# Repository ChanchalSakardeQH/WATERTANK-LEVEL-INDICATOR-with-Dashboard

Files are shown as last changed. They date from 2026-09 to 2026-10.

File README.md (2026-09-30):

<p align="center">
  <a href="https://woodyouloveit.com">woodyouloveit.com</a>
</p>

# Water Tanks Monitor System

**by [woodyouloveit.com](https://woodyouloveit.com)** · © 2026 Chanchal Sakarde. All Rights Reserved. · Open source under [GPL-3.0](LICENSE)

A tank water level indicator using a waterproof ultrasonic sensor, a WS2812B LED strip (1–300 LEDs) and a built-in web dashboard.
The strip fills from the bottom as the water rises: **red at the bottom, fading through yellow to green at the top**.

One sketch runs on both **ESP32 DevKit V1 (30-pin)** and **NodeMCU ESP8266 (30-pin)**. The board is detected automatically from the Arduino IDE board selection.

## Features

- **Web dashboard** for desktop and mobile browsers: live level, calibration, display settings, Wi-Fi settings
- **Usage & tank setup**: Domestic or Commercial, tank location (overhead, loft/bathroom, underground sump), shape and size, with loft tank presets and recommended settings for each
- **Calibration without emptying the tank**: slide to how full the tank is now, or enter measurements. The water depth does the rest.
- **Power saving for production** (default): CPU 80 MHz, fewer sensor reads, LED updates only on change, Wi-Fi power saving, adjustable transmit power, and an on-demand hotspot using the BOOT button
- **Site details**: name each device by society or organisation, building and tank. The names appear on the dashboard, PDF reports and logs, and give every tank its own hotspot name and web address.
- **Wi-Fi setup hotspot** ("WTMS-XXXX", or "WTMS <building> <tank>" once named): connect and the dashboard opens automatically (captive portal)
- **Wi-Fi settings in the dashboard**: scan, connect, forget. The hotspot comes back by itself if home Wi-Fi is unreachable.
- **One-tap calibration** from the dashboard ("Tank is EMPTY now" / "Tank is FULL now") or by typing distances
- **Admin and viewer access**: anyone on the network sees Overview and Analytics; changing settings, logs, clearing history and restarting need the admin password
- **Units**: mm, cm or inches for every measurement (device default, and each viewer can pick their own)
- **Firmware update over Wi-Fi (OTA)** from the dashboard, with board and version checks
- **Update rate profiles**: Eco (default: sensor every 5 s), Balanced, Responsive or Custom
- **Settings backup**: export and import all settings as a file, with a Settings ID printed in reports
- **PDF report** of the analytics, branded with the woodyouloveit.com logo and website ([sample](docs/sample_report.pdf))
- **Tank analytics**: level history, motor run time (fill detection), time to fill, water used per day and by hour, night leak check
- **Connectivity log** saved in flash: restarts and their cause, Wi-Fi and hotspot events, sensor faults, health checks
- Settings saved in flash, kept after restarts and power cuts
- LEDs keep showing the level while the setup hotspot is open
- Works on ESP32 and ESP8266 without code changes
- Red → yellow → green gradient bar, with the top LED partially dimmed for smooth movement
- Median filter (7 samples) plus smoothing to ignore ripples and stray echoes
- Low-water alarm: the bottom 3 LEDs blink red below 10%
- Sensor fault indication: the bottom LED blinks blue. A failed reading never shows a false "full" tank.
- Optional mode where the whole bar changes color with the level
- Serial output of distance and level for calibration

## Hardware

| Qty | Part | Notes |
|---|---|---|
| 1 | ESP32 DevKit V1 (30-pin) **or** NodeMCU ESP8266 (30-pin) | |
| 1 | JSN-SR04T or AJ-SR04M waterproof ultrasonic sensor | Driver board + probe |
| 1 | WS2812B LED strip, 30 or 60 LEDs (1–300 supported) | 5V version. Set the count in the dashboard. |
| 1 | 5V power supply: 2A for 30 LEDs, 3A for 60 LEDs | Powers the board, strip and sensor. The dashboard shows the estimate for your setup. |
| 1 | 330Ω resistor | In series with the LED data line |
| 1 | 1kΩ resistor | Echo voltage divider |
| 1 | 2kΩ resistor | Echo voltage divider |
| 1 | 1000µF capacitor, 10V or higher | Across the strip's 5V and GND |
| 2 | 15-pin female headers | Makes the board removable |
| 3 | Screw terminals (4-pin, 3-pin, 2-pin) | Sensor, LED strip, power |
| 1 | Perfboard, about 7×9 cm | |

## Wiring

### Pin summary

| Connection | ESP32 DevKit | NodeMCU ESP8266 | Notes |
|---|---|---|---|
| LED strip DIN | G16 | D2 (GPIO4) | Through the 330Ω resistor |
| Sensor TRIG (AJ-SR04M RX) | D15 | D5 (GPIO14) | Direct |
| Sensor ECHO (AJ-SR04M TX) | D2 | D6 (GPIO12) | ESP32: direct, sensor on 3V3. ESP8266: 1k/2k divider, or direct with the sensor on 3V3 |
| Sensor power | 3V3 | VIN or 3V3 | ESP32: 3V3 only, see below |
| +5V | VIN | VIN | From the 5V supply |
| GND | GND | GND | All grounds connected together |

### ESP32 DevKit V1 (30-pin)

On the ESP32 the sensor uses four neighbouring pins, **3V3 · GND · D15 · D2**, so one 4-pin connector or a short row of jumper wires does the job:

| ESP32 pin | AJ-SR04M pin |
|---|---|
| 3V3 | 5V (runs fine on 3.3V) |
| GND | GND |
| D15 | RX (TRIG) |
| D2 | TX (ECHO) |

ESP32 wiring diagram

> **Keep D15 = TRIG and D2 = ECHO, and power the sensor from 3V3.** D15 and D2 are boot "strapping" pins that the ESP32 reads at start-up.
> D2 must be LOW while uploading over USB. The sensor's echo output rests LOW, so uploads work. The sensor's RX input could hold D2 HIGH, so swapping the two wires can make uploads fail.
> With the sensor on 3V3, the echo is 3.3V and needs no divider. Powering the sensor from 5V would put 5V into D2.
> If your board has a blue LED on D2, it will flicker with each measurement. That's normal.
> If an upload ever fails with "wrong boot mode", unplug the sensor connector, upload, and plug it back in.

### NodeMCU ESP8266 (30-pin)

NodeMCU ESP8266 wiring diagram

### NodeMCU ESP8266 with AJ-SR04M on 3.3V (no divider)

The AJ-SR04M is rated for 3.0–5.5V. Powered from the NodeMCU's 3V3 pin, its echo output is 3.3V, so it can connect directly to D6 with no resistors. On this board, **RX = TRIG** and **TX = ECHO**. Range may be shorter than at 5V, so test at your tank's full depth.

NodeMCU ESP8266 3.3V wiring diagram

> **Warning:** In this setup the sensor's 5V pin must go to **3V3 only**. Connecting it to the 5V supply would put 5V straight into D6.

### Why the extra parts

- **1k/2k divider on ECHO:** The sensor's echo output is 5V, but both boards are 3.3V chips. The divider brings the signal down to about 3.3V.
- **330Ω on DIN:** Reduces ringing on the data line and protects the first LED. Place it close to the strip.
- **1000µF capacitor:** Absorbs the current surge when the strip switches on. Mind the polarity: the striped side goes to GND.
- **External 5V supply:** Each LED can draw up to 60mA at full white, so 60 LEDs can need over 3A. The level display uses less (red/green only), and the dashboard shows an estimate for your LED count and brightness. Don't power the strip from the board's USB port.

> **ESP8266 note:** Avoid D3, D4 and D8 for external wiring. The board reads them at boot, and anything connected there can stop it from starting.

## Software setup

1. Install the [Arduino IDE](https://www.arduino.cc/en/software).
2. Add the board package for your board:
   - **ESP32:** In Boards Manager, install "esp32" by Espressif.
   - **ESP8266:** In Preferences → Additional Boards Manager URLs, add
     `http://arduino.esp8266.com/stable/package_esp8266com_index.json`,
     then install "esp8266" from Boards Manager.
3. Install **Adafruit NeoPixel** from Library Manager. Wi-Fi, web server, DNS and mDNS come with the board package.
   The WiFiManager library used by 2.0.0 is no longer needed.
4. Open `water_level_indicator/water_level_indicator.ino`. The dashboard page (`dashboard_html.h`) opens as a second tab.
5. Select the board in **Tools → Board**:
   - ESP32: **ESP32 Dev Module**
   - ESP8266: **NodeMCU 1.0 (ESP-12E Module)**, with **Flash Size: 4MB (FS:2MB OTA:~1019KB)** so the log can be saved in flash
6. Check the **Tools** settings below, upload, then open Serial Monitor at **115200 baud**. The first line shows the firmware version and board.

**Tools settings (ESP32 Dev Module)**

| Setting | Use | Why |
|---|---|---|
| Erase All Flash Before Sketch Upload | **Disabled** | Enabled wipes Wi-Fi, site details, tank setup, calibration, history and logs on every upload |
| Partition Scheme | Default 4MB with spiffs (1.2MB APP / 1.5MB SPIFFS) | The log and history are stored in the "spiffs" area (used by LittleFS) |
| CPU Frequency | 240MHz or 80MHz | Either is fine. In power saving mode the firmware switches to 80 MHz itself. |
| Core Debug Level | None | Keeps the Serial Monitor readable |
| Upload Speed | 921600 | Lower it to 115200 if uploads fail |

**Tools settings (NodeMCU 1.0)**: Flash Size **4MB (FS:2MB OTA:~1019KB)**, Erase Flash **Only Sketch**.

After the very first upload, or after an upload with erase enabled, the flash storage is blank. The firmware formats it by itself and logs
"Flash storage was blank and has been formatted", and the boot counter starts at #1. That's normal.
Settings then need to be entered once in the dashboard.

## First-time Wi-Fi setup

1. Power the device. With no home Wi-Fi saved, it opens the hotspot **WTMS-XXXX** (XXXX is unique to each board) and the top LED blinks blue.
2. Connect your phone or laptop to that hotspot. The dashboard opens automatically.
   If it doesn't, open a browser and go to `http://192.168.4.1`.
3. In **Wi-Fi settings**, press **Scan**, pick your network, enter the password and press **Connect**.
4. The dashboard shows the new address (`http://watertank-xxxx.local` or the IP). The hotspot turns off 30 seconds later.
5. In **Site details**, enter the society or organisation, building and tank names, save, and restart the device (see below).
   Switch your phone or PC back to your home Wi-Fi and open that address.

If the device can't reach your home Wi-Fi (router off, wrong password, moved too far), the hotspot turns back on automatically.
The device retries your home network every minute while nobody is connected to the hotspot.

No home Wi-Fi at the tank? Just leave it on the hotspot and use `http://192.168.4.1`.

## Site details (society, building, tank)

Every device is named in the **Site details** card on the Overview tab:

| Field | Example | Max length |
|---|---|---|
| Society / organisation | NYATI | 48 |
| Building | YUCCA | 32 |
| Tank | Overhead Tank 1 | 32 |

The names are used:
- **on the dashboard:** header ("YUCCA · Overhead Tank 1", with the society underneath), browser tab title and footer
- **in the PDF report:** site title, a details table, page headers, document properties and the file name, e.g. `wtms-report-yucca-overhead-tank-1-20260930.pdf`
- **in the downloaded connectivity log** header and file name

The **hotspot name** and **web address** are made from the building and tank names, so several tanks in one society don't clash:

| Site details | Hotspot name | Web address |
|---|---|---|
| Not set | `WTMS-3F2A` (from the chip ID) | `http://watertank-3f2a.local` |
| YUCCA / Overhead Tank 1 | `WTMS YUCCA Overhead Tank 1` | `http://tank-yucca-overhead-tank-1.local` |
| Tower A / Tank #2 (Sump) | `WTMS Tower A Tank #2 (Sump)` | `http://tank-tower-a-tank-2-sump.local` |

The card previews both before you save. They take effect after **Restart device**. Hotspot names are cut to 32 characters (a Wi-Fi limit), so keep building and tank names short.
WTMS stands for Water Tanks Monitor System.

## Dashboard

Open the dashboard from any device on the same network:

- `http://<web address>.local`, shown in **Site details** (Windows, macOS, iOS, Linux; some Android phones don't support `.local`)
- or the device's IP address, shown in Serial Monitor and in your router's device list

| Desktop | Mobile |
|---|---|
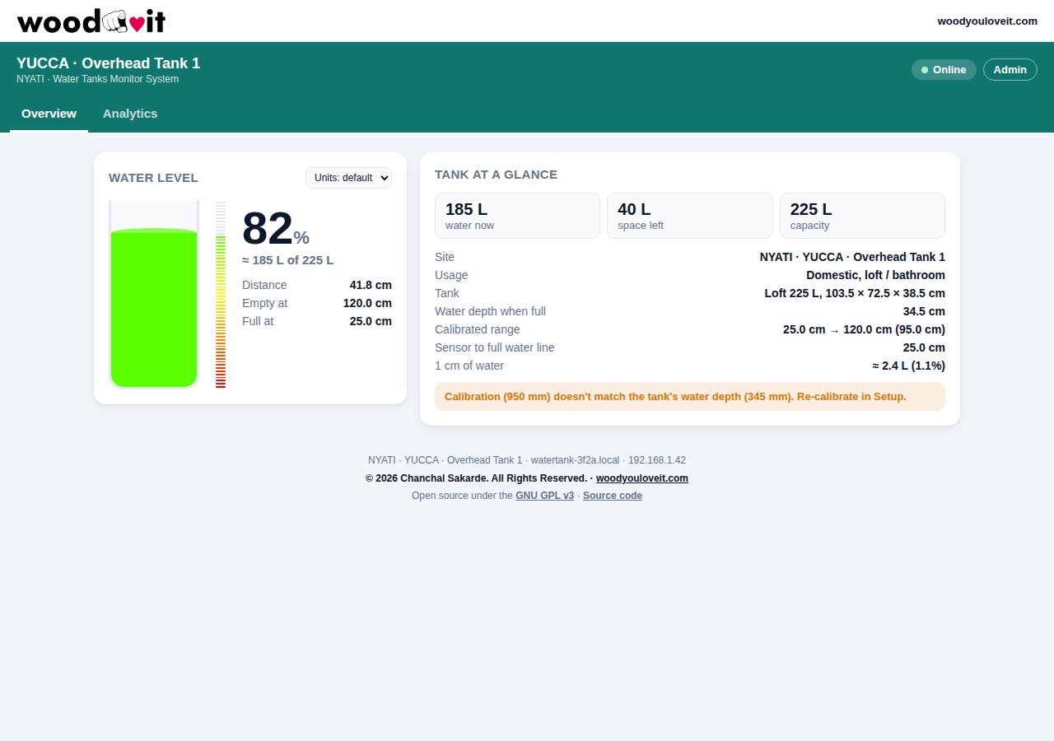
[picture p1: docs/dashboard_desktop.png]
Dashboard on desktop
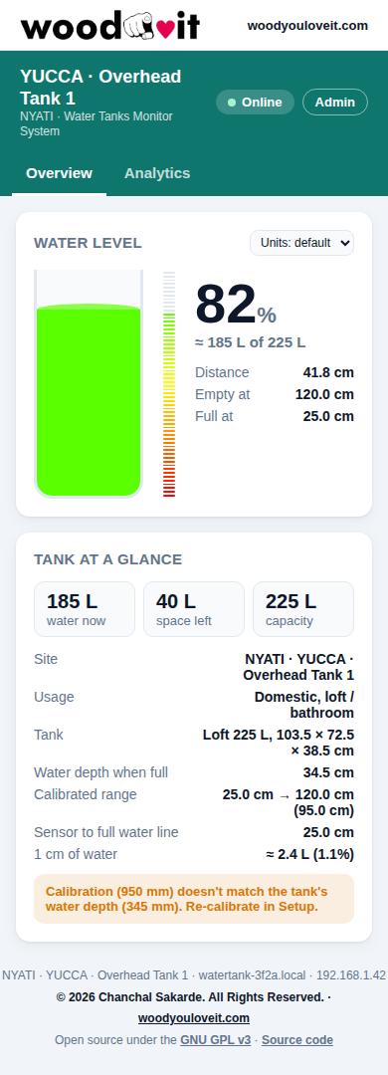
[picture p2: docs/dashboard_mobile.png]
Dashboard on mobile
|  |  |

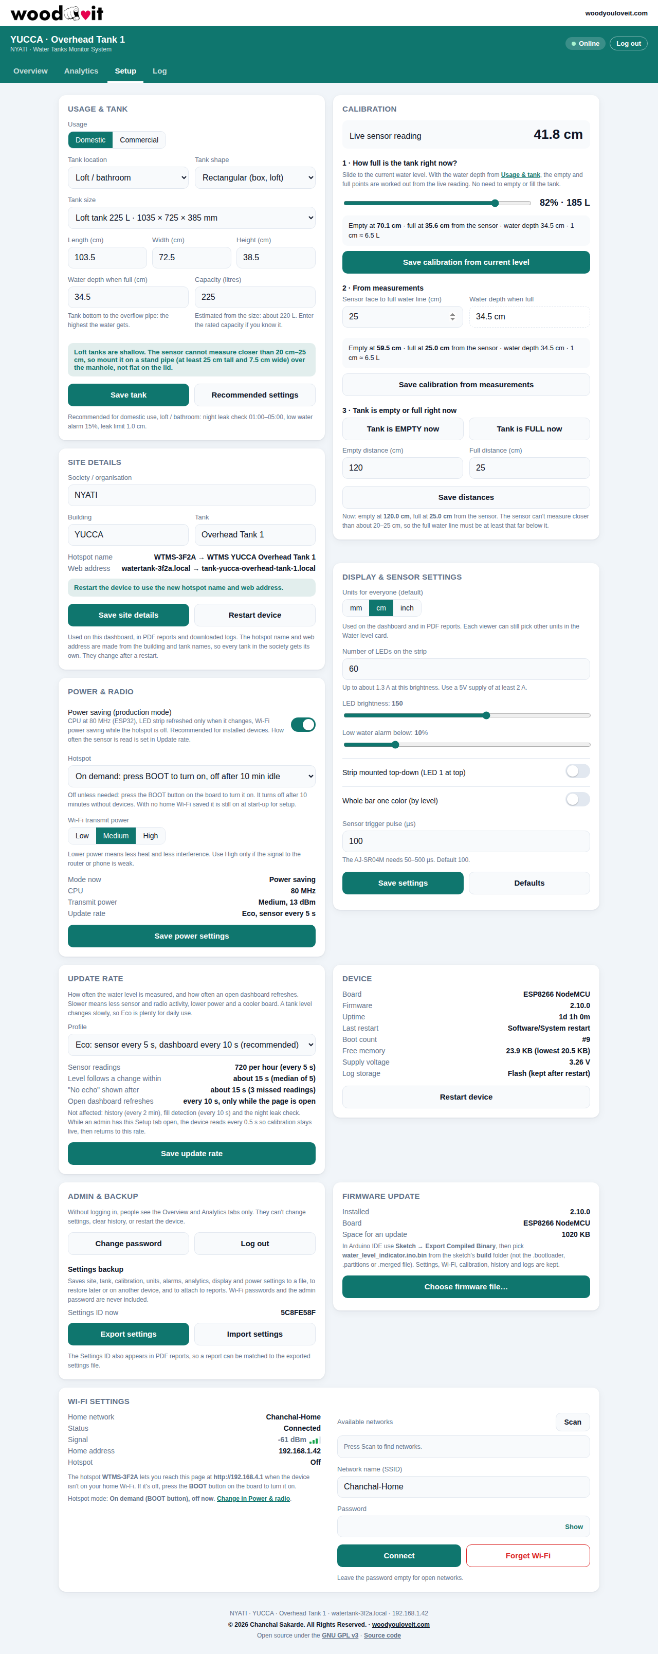
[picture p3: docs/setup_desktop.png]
Setup tab


The dashboard has four tabs: **Overview**, **Analytics**, **Setup** and **Log**.

| Tab · card | What it does |
|---|---|
| Overview · Water level | Live level in % and litres, tank graphic and LED strip preview. Shows sensor fault, low water, filling and leak alerts. |
| Overview · Tank at a glance | Water now, space left, capacity, site, usage, tank size, water depth, calibrated range, litres per cm, and setup warnings |
| Setup · Usage & tank | Domestic / Commercial, location, shape, size (loft presets or custom), water depth, capacity, **Recommended settings** |
| Setup · Calibration | Current-level slider, calibration from measurements, EMPTY / FULL buttons, manual distances |
| Setup · Site details | Society / organisation, building and tank names |
| Setup · Display & sensor | LED brightness, low water alarm, strip direction, color mode, trigger pulse. **Defaults** restores factory settings. |
| Setup · Wi-Fi settings | Saved network, status, signal, home address and hotspot state. **Scan** lists nearby networks, **Connect** joins one (saved only if it works), **Forget Wi-Fi** erases the saved network. |
| Setup · Device | Board, firmware, uptime, cause of the last restart, boot count, free memory, supply voltage (ESP8266), **Restart device**. |
| Log | Every restart, Wi-Fi and hotspot event with time, filters, **Download** and **Clear**. See below. |

## Configuration

All of these settings can be changed from the dashboard and are saved in flash. The table shows the factory defaults.

| Setting | Default | Description |
|---|---|---|
| Number of LEDs | `30` | 1–300. Kept when you press **Defaults**. |
| Empty distance | `120` cm | Distance from the sensor to the water surface when the tank is empty |
| Full distance | `25` cm | Distance when the tank is full. Keep this at 20–25 or more (sensor blind zone). |
| LED brightness | `150` | 5–255 |
| Strip mounted top-down | off | Turn on if LED #1 is at the top of the tank |
| Whole bar one color | off | On: the whole bar is red when low and green when full |
| Low water alarm | `10` % | Level below which the bottom LEDs blink red |
| Trigger pulse | `100` | Trigger pulse length in µs. The AJ-SR04M ignores 10–20µs pulses. |

Fixed in the sketch: `MAX_VALID_CM` (450), readings above it are treated as "no target". The hotspot name (`AP_NAME`) and hostname (`HOSTNAME`) are also defined at the top of the sketch.

The pin numbers for each board are in the `#if defined(ESP32)` / `#elif defined(ESP8266)` block.

### Usage & tank (Setup tab)

| Setting | Options | What it changes |
|---|---|---|
| Usage | Domestic, Commercial | Recommended night leak window and low water alarm; shown in reports |
| Tank location | Overhead (roof), Loft / bathroom, Underground sump, Other | Mounting tips and recommended low water alarm |
| Tank shape | Rectangular (box, loft), Vertical cylinder | Which dimensions are asked and how capacity is estimated |
| Tank size | Loft presets or custom length × width × height / diameter × height (mm) | Tank details in the dashboard and reports |
| Water depth when full | mm, tank bottom to the overflow pipe | Used by the calibration slider and measurement method |
| Capacity | litres | Litres everywhere (level, analytics, reports) |

**Loft tank presets** (rated capacity, outer size in mm):

| Capacity | Length | Width | Height | Water depth preset |
|---|---|---|---|---|
| 150 L | 710 | 710 | 400 | 360 |
| 225 L | 1035 | 725 | 385 | 345 |
| 270 L | 1100 | 735 | 425 | 385 |
| 400 L | 1120 | 875 | 420 | 380 |
| 500 L | 1450 | 915 | 445 | 405 |
| 1000 L | 1650 | 1080 | 685 | 645 |

The preset water depth is the tank height minus 40 mm. Measure your overflow pipe and correct it if needed.
Outer dimensions overstate capacity by 3–26% (walls, ribs, sloped top), so the rated capacity is used for litres, not length × width × height.

**Recommended settings** (button in Usage & tank, applied only when you confirm):

| | Domestic | Commercial |
|---|---|---|
| Night leak check | 01:00–05:00 | 22:00–06:00 (after hours) |
| Low water alarm | 15% (30% for a sump) | 25% (30% for a sump) |
| Leak limit | 2% of the water depth, at least 1 cm | same |

### Calibration (Setup tab)

Pick whichever is easiest. All three give the same result: the sensor distance at **empty** and at **full**.

1. **How full is the tank right now?** Set **Water depth when full** in Usage & tank, then slide to the current level (e.g. 70%) and save.
   The firmware works out: empty = live reading + level × depth, full = empty − depth. No need to empty or fill the tank.
2. **From measurements:** enter the distance from the sensor face to the full (overflow) water line. Empty = that distance + water depth.
3. **Tank is EMPTY / FULL now** buttons, or type both distances.

Each method previews the result and warns if the full water line is inside the sensor's blind zone.

**Sensor blind zone, especially on loft tanks.** The AJ-SR04M / JSN-SR04T can't measure closer than about 20–25 cm.
Loft tanks are only 385–685 mm tall, so a sensor mounted flat on the lid would miss the top half of the tank.
Mount it on a **stand pipe at least 25 cm tall and 75 mm wide** over the manhole, so the full water line is 25 cm or more below the sensor face.
On a shallow tank, 1 cm of water is about 2.5% of the tank (≈ 6 L in a 225 L loft tank). That's the resolution you can expect.

## How it works

```
level = (empty distance - distance) / (empty distance - full distance)    clamped to 0..1
LEDs lit = level × number of LEDs, counting from the bottom of the strip
LED color = its position on the strip: bottom red → middle yellow → top green
```

The sensor is read every 70ms and the median of the last 7 readings is used. The level is then blended with the previous value so the bar moves smoothly. Ten misses in a row show the sensor fault blink.

## Power, heat and production use

The ESP32 runs warm mainly because of the Wi-Fi radio. A hotspot can't use Wi-Fi power saving, and full transmit power is far more than a phone next to the tank needs.
The **Power & radio** card (Setup tab) controls this:

| Setting | Options | Default |
|---|---|---|
| Power saving (production mode) | on / off (performance) | **on** |
| Hotspot | Automatic, On demand (BOOT button), Always on | Automatic |
| Wi-Fi transmit power | Low 8.5 dBm, Medium 13 dBm, High 19.5 dBm | **Medium** |

| | Power saving (default) | Performance |
|---|---|---|
| CPU (ESP32) | 80 MHz | 240 MHz |
| LED strip | refreshed 4 times a second, only when something changed | 10 times a second |
| Wi-Fi | modem sleep while the hotspot is off | always awake |
| Main loop | pauses 5 ms per pass | pauses 1 ms per pass |
| Serial output | log lines only | log lines + live distance every second |
| Dashboard refresh | every 2 s | every second |

**Hotspot modes**
- **Automatic:** on while there's no home Wi-Fi or it can't be reached; off 30 s after home Wi-Fi connects.
- **On demand:** best for installed devices. The hotspot stays off until someone presses the **BOOT** button on the ESP32 (the **FLASH** button on a NodeMCU). It turns off after 10 minutes without devices connected. With no home Wi-Fi saved it still starts for setup, and with no home Wi-Fi and no hotspot the radio is switched off completely.
- **Always on:** only if you really need it. It uses the most power and runs warmest.

The top LED blinks blue whenever the hotspot is on. Every change is recorded in the connectivity log.

**Recommended production setup:** power saving on, hotspot on demand, transmit power Low or Medium (Medium if the router is in another room).

**Other heat sources**
- **The 3.3V regulator** next to the USB socket turns 5V into 3.3V for the ESP32 and the sensor. It gets warm, and that's normal. If it's too hot to touch, check for a short on 3V3 and make sure the LED strip is powered from the 5V supply, not through the board.
- **The enclosure:** leave a few ventilation holes, and don't mount the board against the LED strip or in direct sun.

## Admin and viewer access

| | Viewer (no login) | Admin |
|---|---|---|
| Overview tab (level, litres, tank at a glance) | ✓ | ✓ |
| Analytics tab (charts, fills, night check, PDF report) | ✓ | ✓ |
| Analytics settings: save, clear history | view only | ✓ |
| Setup tab (tank, calibration, site, display, power, Wi-Fi, device, backup) | hidden | ✓ |
| Log tab | hidden | ✓ |
| Restart the device, reset to defaults | ✗ | ✓ |

- Press **Admin** in the header to log in. The **default password is `admin`**, and it must be changed at the first login (at least 6 characters).
- **Forgot the password?** Hold the **BOOT** button (ESP32) or **FLASH** button (NodeMCU) for **10 seconds** until the strip flashes red. The password goes back to `admin`.
- An admin session ends after 12 hours without activity, or when the device restarts. Up to 3 admin sessions can be open at once.
- After 5 wrong passwords, login is blocked for a minute. Logins, failed logins and password changes are recorded in the log.
- **Security note:** the password itself never crosses the network. The browser answers a one-time challenge with a SHA-256 proof, and only a salted hash is stored on the device. The dashboard uses plain HTTP, though, so on an untrusted network the session token could be observed. Keep the device on your own Wi-Fi.

## Units

All measurements can be shown in **mm**, **cm** or **inches**: distances, tank dimensions, water depth, calibration, leak limit, fill speed, the "1 unit of water = X L" resolution, and the PDF report.

- **Admin default for everyone:** Setup → Display & sensor → *Units for everyone*.
- **Per browser:** the *Units* menu in the Water level card overrides the default on that phone or PC only.

The device always stores centimetres and millimetres internally, so switching units never changes the calibration.

## Settings backup and the Settings ID

Setup → **Admin & backup**:
- **Export settings** downloads a JSON file with the site, tank profile, calibration, capacity, alarms, analytics, units, display, sensor and power settings.
- **Import settings** restores such a file, on this device or another one. Wi-Fi is not changed.
- Wi-Fi passwords and the admin password are **never** exported.

The **Settings ID** is an 8-character fingerprint of those settings. It's shown in the Admin card, in the exported file, in the PDF report's details and footer, and in the report's **"Settings used for this report"** page.
Anyone checking a report can confirm which configuration produced its figures by matching the ID with an exported settings file.

## Update rate

How often the sensor is read and how often an **open** dashboard refreshes (Setup → **Update rate**):

| Profile | Sensor reading | Median of | Level follows a change within | "No echo" after | Dashboard refresh |
|---|---|---|---|---|---|
| **Eco** (default) | every 5 s (720/hour) | 5 | ~15 s | ~15 s | every 10 s |
| Balanced | every 2 s | 5 | ~6 s | ~14 s | every 5 s |
| Responsive | every 0.5 s | 7 | ~2 s | ~5 s | every 2 s |
| Custom | 0.2–30 s | 5 or 7 | shown in the card | shown in the card | 2–60 s |

- The dashboard refresh only happens while someone has the page open. With no page open, the device serves nothing.
- History (every 2 min), fill detection (every 10 s) and the night leak check don't depend on the profile.
- **Live mode for calibration:** while an admin has the Setup tab open, the device reads every 0.5 s and the page refreshes every 2 s.
  It returns to the saved profile 20 s after the Setup tab is closed.
- The biggest continuous power user is the Wi-Fi radio, not the sensor. For the coolest, longest-lived setup, combine **Eco** with **Power saving**, the **On demand** hotspot and **Low/Medium** transmit power.

## Firmware update over Wi-Fi (OTA)

Setup → **Firmware update** (admin only):

1. In Arduino IDE, with the same board settings as before, choose **Sketch → Export Compiled Binary**.
2. In the sketch folder, open `build/<board>/` and take **`water_level_indicator.ino.bin`**, not the `.bootloader`, `.partitions` or `.merged` files.
3. In the dashboard, press **Choose firmware file…**. Before uploading, the dashboard checks that:
   - it's an ESP firmware file
   - it's Water Tanks Monitor System firmware for **this** board (ESP32 or ESP8266)
   - it fits in the free space

   It also shows the version and warns about downgrades.
4. Confirm. A progress bar shows the upload. The device verifies the image, restarts, and the page reports the new version.

**Kept:** settings, Wi-Fi, admin password, calibration, history and logs.
**Safety:** the new firmware goes into the spare program slot. If the upload is interrupted or the image fails verification, the current firmware keeps running.

**Size limits:**
- **ESP32** (Partition Scheme "Default 4MB with spiffs"): two 1.2 MB program slots. Anything that fits by USB fits OTA.
- **ESP8266 NodeMCU:** the new program is written next to the running one inside a ~1 MB area, so OTA works only while the program is under about **500 KB**. The card shows the space available. If a build is too big, update once by USB.

Every update and failure is recorded in the connectivity log.

## Tank analytics

The **Analytics** tab turns the level history into answers about your tank. The device records the level every 2 minutes in flash (14 days)
and detects fills itself from 10-second samples. The charts are calculated in your browser, in your local time.

| Section | What it shows |
|---|---|
| Summary tiles | Level now (or **Filling** with rise speed and time until full), last fill, how long empty → full takes, motor time today, water used today, busiest hour, last night's leak check |
| Level history | 24 h / 3 / 7 / 14 days, with fills (motor on) and the night check window shaded. Hover or tap for exact values. |
| Motor run time per day | Total filling time for the last 7 days, and the 5 most recent fills with duration and amount |
| Water used per day | Level drops outside fills, for the last 7 days |
| Usage by hour of day | Average use for each hour, busiest 3 hours highlighted |
| Night leak check | Level change in a quiet window (default 01:00–05:00) for the last 7 nights |

**How it decides**
- **Filling / motor on:** the level rises faster than the fill threshold (default 0.5 cm/min) by at least 1.5 cm. Filling ends when the rise slows down or the tank is full. Fills shorter than 3 minutes or 3 cm are ignored. The device assumes every fill is the motor.
- **Water used:** every drop in level outside a fill, with a small dead band so sensor noise isn't counted as use.
- **Night leak check:**
  - **Possible leak:** the level drops by more than the limit (default 1.5 cm) slowly and steadily, with no fill running.
  - **Water used (one drop):** most of the drop happened within one hour, like a tap or a flush.
  - **Watch:** the drop is between half the limit and the limit.
  - A leak warning for last night also shows on the Overview tab.

**Analytics settings** (bottom of the Analytics tab)
- **Tank capacity (litres):** optional. With it, amounts show in litres; without it, in %. This assumes straight tank walls, so the litres are approximate for tapered tanks.
- **Fill detection threshold:** lower it if slow fills are missed, raise it if you see false fills.
- **Night check window and leak limit:** pick hours when nobody normally uses water.
- **Clear history** erases the recorded levels and fills.

History needs the real time. That comes from the internet on home Wi-Fi, or from your browser when you open the dashboard on the hotspot.
Distances are stored rather than %, so re-calibrating later also corrects old history.

| Desktop | Mobile |
|---|---|
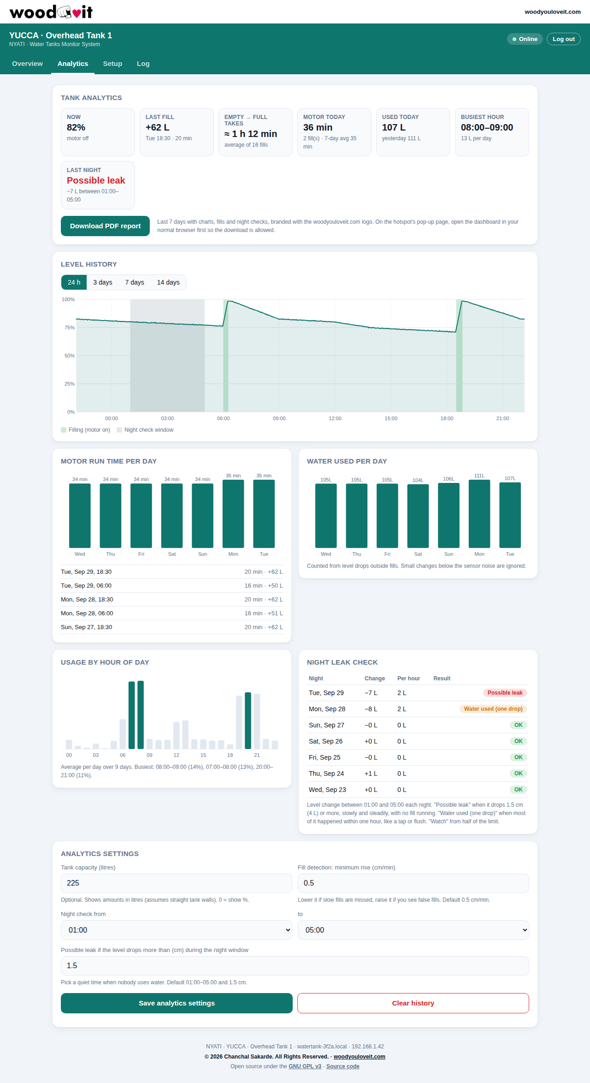
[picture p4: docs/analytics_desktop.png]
Analytics on desktop
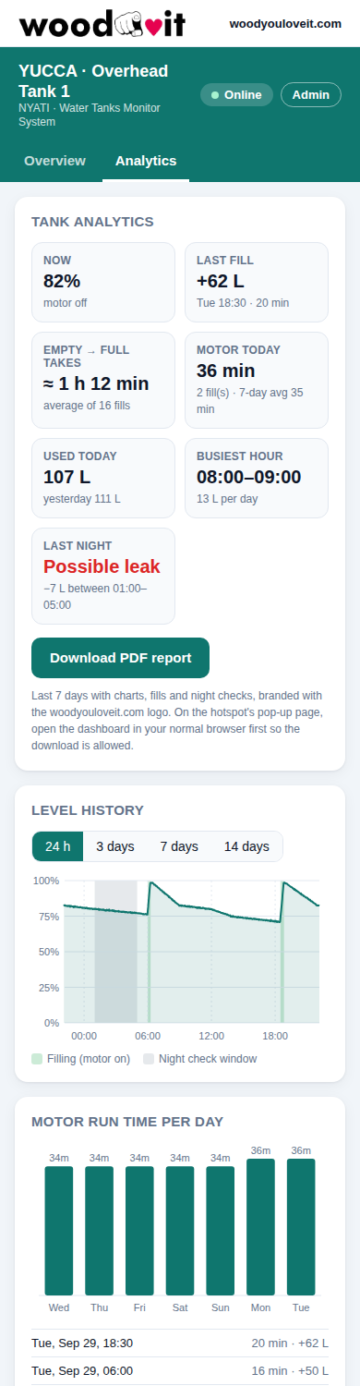
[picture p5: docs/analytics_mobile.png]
Analytics on mobile
|  |  |

### PDF report

In the **Analytics** tab, press **Download PDF report**. The report is created in your browser (it works offline on the hotspot too) and covers the last 7 days:

- **Page 1:** woodyouloveit.com logo and website, report date and period, device and tank details, summary tiles, 7-day level history chart, motor run time and water used per day
- **Page 2:** usage by hour of day, night leak check table, recent fills, how the numbers are calculated
- **Page 3:** "Settings used for this report": calibration, capacity, resolution, units, alarm limits, night window, leak and fill thresholds, recording intervals, power mode, firmware and the Settings ID
- **Every page:** © 2026 Chanchal Sakarde. All Rights Reserved., woodyouloveit.com, page number, firmware and Settings ID

See the [sample report](docs/sample_report.pdf) (made from simulated data).
If you opened the dashboard from the hotspot's pop-up window, open `http://192.168.4.1` in your normal browser first. Some pop-up windows don't allow downloads.

## Connectivity log

The device records events in flash, so they survive restarts and power cuts (about 300–400 events, oldest dropped first).
Open the **Connectivity log** card in the dashboard, or download it as a text file to share.

| Event | What it tells you |
|---|---|
| `Boot #N ... restart cause: ...` | Every start. **Power on** means power was cut or dipped; **Watchdog**, **Exception**, **Crash** or **Brownout** mean a problem (shown in red). |
| `Supply voltage` (ESP8266) | The board's 3.3V rail at boot and every 5 minutes. Below 3.0V means the supply is struggling. |
| `Hotspot on / off (reason)` | When and why the hotspot changed. "connected to home Wi-Fi" is normal. |
| `Device joined / left hotspot` | Phones and PCs connecting to the hotspot, by MAC address. |
| `Hotspot channel changed` | The ESP8266 hotspot must use the same channel as the home Wi-Fi. When it changes, devices on the hotspot are disconnected briefly. |
| `Home Wi-Fi lost / disconnect event` | With the reason, e.g. "signal lost (beacon timeout)" or "wrong password?". |
| `Health` (every 5 min) | Free memory, supply voltage, slowest main loop, hotspot clients, Wi-Fi signal and channel. |
| `Main loop was blocked` | Something stalled the firmware for more than 2 s. |
| `Sensor fault / Sensor OK` | Ultrasonic sensor stopped or started answering (at most once per 30 s). |

Times come from the internet when on home Wi-Fi, or from your browser when you open the dashboard on the hotspot.
Before that, events show as `Boot #N +h:mm:ss` (time since that start).

**Reading a "hotspot disappears" problem**
- Many `Boot #` lines with **Power on** and a low supply voltage: the board is resetting from power dips. Use a 5V supply that can handle the LED strip, not USB.
- `Hotspot off (connected to home Wi-Fi)`: expected. Turn on **Keep hotspot always on** in Wi-Fi settings if you want it to stay.
- `Hotspot channel changed`: the device is joining or retrying your home Wi-Fi on another channel.
- `Home Wi-Fi lost: signal lost`: weak signal at the tank. The device switches to the hotspot until the home Wi-Fi is back.

## LED indications

| Display | Meaning |
|---|---|
| Red → green sweep at power-up | Startup test |
| Top LED blinking blue | The device's hotspot is on |
| Bar from the bottom | Current water level |
| Bottom 3 LEDs blinking red | Water below 10% |
| Bottom LED blinking blue | No echo from the sensor. Check the wiring, the divider and the probe position. |

## Troubleshooting

| Problem | Things to check |
|---|---|
| LEDs flicker or show random colors | Common ground between the supply, board and strip; the 330Ω resistor; the capacitor. A 74AHCT125 level shifter on DIN helps with long wires. |
| Blue blink (no echo) | ECHO divider wiring; sensor powered from 5V; probe too close to the water (inside the 25cm blind zone) |
| Level jumps around | Probe not vertical, or the beam hits the tank wall or pipes |
| Only part of the strip lights up at full level | Set **Number of LEDs on the strip** in Display & sensor settings to match your strip. |
| Bar fills from the wrong end | Turn on **Strip mounted top-down** in the dashboard |
| Blue blink with an AJ-SR04M | Run `tools/sensor_diagnostic` to check the wiring and find a working trigger width |
| Dashboard doesn't open by itself on the hotspot | Open a browser and go to `http://192.168.4.1`. On Android, tap the "Sign in to network" notification. |
| Hotspot connects but the page never loads | Type `http://192.168.4.1` exactly (with `http://`). Other sites and `https://` addresses can't be redirected. On a phone, turn off mobile data while setting up. Check Serial Monitor: repeating `Boot #` lines mean the board keeps restarting. |
| Hotspot disappears | Open the **Connectivity log**. See "Reading a hotspot disappears problem" above. |
| Device card says "Log storage: Memory only" | On ESP8266, select **Tools → Flash Size → 4MB (FS:2MB OTA:~1019KB)** and upload again. |
| The `.local` address doesn't open | Use the IP address instead. Some Android phones don't support `.local` names. |
| Serial shows `esp_littlefs ... Corrupted dir pair` or `mount failed (-84)` (firmware 2.8.0 and older) | The flash storage was blank, usually because **Erase All Flash Before Sketch Upload** is Enabled. The firmware formats it automatically. Set that option to Disabled so settings survive uploads. |
| Settings, Wi-Fi or calibration lost after an upload | **Tools → Erase All Flash Before Sketch Upload** must be **Disabled** (ESP32), or **Erase Flash: Only Sketch** (NodeMCU). |
| Hotspot doesn't appear | In on-demand mode it's off until you press **BOOT** (ESP32) or **FLASH** (NodeMCU). The top LED blinks blue when it's on. |
| Board gets hot | Turn on **Power saving**, set the hotspot to **On demand**, and lower the transmit power. See "Power, heat and production use". |
| Dashboard unreachable after changing the router | Wait about 20 seconds: the hotspot turns on by itself. Connect to it and choose the new network in Wi-Fi settings. |
| ESP8266 won't boot with the circuit connected | Make sure nothing is connected to D3, D4 or D8 |

## Branding

The woodyouloveit.com brand appears on:

- the dashboard (logo bar, page title, footer with copyright and website, heart icon in the browser tab)
- the PDF report (logo, website and copyright on every page, and in the document properties)
- the downloaded connectivity log, the Serial Monitor start-up message, and the wiring diagrams
- the header of every source file

The logo is built into the firmware (`dashboard_html.h`), so it shows even without internet. The original is in `docs/logo.png`.

## License

Copyright (C) 2026 Chanchal Sakarde, [woodyouloveit.com](https://woodyouloveit.com). All Rights Reserved, except as granted by the license below.

This project is free software: you can redistribute it and/or modify it under the terms of the
**GNU General Public License** as published by the Free Software Foundation, either version 3 of the License,
or (at your option) any later version. It is distributed in the hope that it will be useful, but **without any warranty**.
See [LICENSE](LICENSE) for the full text.

Every source file carries this notice and `SPDX-License-Identifier: GPL-3.0-or-later`.
If you share a modified version, keep the copyright notices and publish your source code under the same license.

## Project structure

```
water-level-indicator/
├── water_level_indicator/
│   ├── water_level_indicator.ino   # Sketch for ESP32 and ESP8266
│   ├── dashboard_html.h            # Web dashboard page (HTML/CSS/JS)
│   ├── auth.h                      # Admin login: SHA-256, password, sessions
│   ├── event_log.h                 # Connectivity log stored in flash (LittleFS)
│   └── history.h                   # Level history and fill (motor) detection
├── docs/
│   ├── wiring_esp32.svg            # ESP32 wiring diagram
│   ├── wiring_esp8266.svg          # NodeMCU wiring diagram
│   ├── wiring_esp8266_3v3.svg      # NodeMCU, sensor on 3.3V, no divider
│   ├── wiring_*.png                # PNG versions of the diagrams
│   ├── dashboard_*.png             # Dashboard screenshots
│   ├── setup_desktop.png           # Setup tab screenshot
│   ├── analytics_*.png             # Analytics screenshots
│   ├── logo.png                    # woodyouloveit.com logo
│   ├── sample_report.pdf           # Example PDF report (simulated data)
│   └── gen_diagrams.py             # Regenerates the diagrams
├── tools/
│   └── sensor_diagnostic/          # Sensor wiring and mode test sketch
├── CHANGELOG.md
├── LICENSE                         # GNU General Public License v3
├── README.md
└── .gitignore
```

To regenerate the diagrams after editing `docs/gen_diagrams.py`:

```bash
pip install cairosvg
python docs/gen_diagrams.py
```

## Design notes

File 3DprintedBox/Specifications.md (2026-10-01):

The enclosure is ready: two STL files to print, plus the OpenSCAD source for adjusting sizes.

**Size:** 130 × 51 × 36 mm for the box. With the mounting ears it's 154 mm long, and the lid adds 2.4 mm on top.

**What's in the design:**

- **Probe passage** in the right-hand wall, next to the JSN board.
- **Power passage** in the back wall. I also added a **third passage for the LED strip's 3 wires**, since they have to leave the box too; it can be switched off with one setting.
- All three passages are **slots open at the top**. You lay the cable in, connector and all; the probe's white plug wouldn't fit through a small round hole. The lid has tongues that close each slot and lightly clamp the cable.
- **5V fan:** a 30 × 30 × 10 mm fan (24 mm hole spacing) screws to the underside of the lid and blows out through a grille. Air comes in through slots low in the front wall. 25 mm and 40 mm fans are a one-number change, or you can turn the fan off and get plain lid vents.
- **Holes over the BOOT and RST buttons,** labelled, so you can press them with a pen. BOOT is needed for the on-demand hotspot and the password reset.
- **Micro-USB opening** for programming, and **wall-mounting ears**.
- **Corner cradles** hold both boards 15 mm above the floor, leaving room for the header pins and jumper wires underneath.
- **The lid is engraved** with "Water Tanks Monitor" and "woodyouloveit.com".

**Printing:**

- Print the box with the open side up, and the lid top face down. Neither needs supports.
- Use PETG or ASA if it will sit near heat or sun; PLA is fine indoors.
- Settings: 0.2 mm layers, 3 walls, 20% infill.

**Hardware:**

- 4 × M3 × 8–10 mm screws for the lid.
- 4 × M3 × 8 mm screws for the fan.
- 2 wall screws for the ears.

Connect the fan to **5V and GND** (VIN and GND), never to 3V3.

**Before printing, measure three things with calipers.** If any differ from these defaults, change them at the top of the `.scad` file and export again from OpenSCAD (free):

1. **ESP32 board size:** set as 51.5 × 28.5 mm; clone boards vary slightly. The JSN board uses your spec sheet's 41.3 × 29 mm.
2. **Probe cable diameter:** set as 5.0 mm.
3. **Power cable diameter:** set as 5.5 mm.

**Note:** with a fan and vents, the box is **not splash-proof**. Mount it under cover, out of rain and direct sun, with the passages facing down or sideways.

Try Creating Box : [ChanchalSakardeQH/3d-Box-STL-FILE-Generator: Parametric 3D box generator with dividers, lids, and text engraving — exports STL files for 3D printing, entirely in the browser.](https://github.com/ChanchalSakardeQH/3d-Box-STL-FILE-Generator)

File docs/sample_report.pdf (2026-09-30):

# Tank Analytics Report

# NYATI

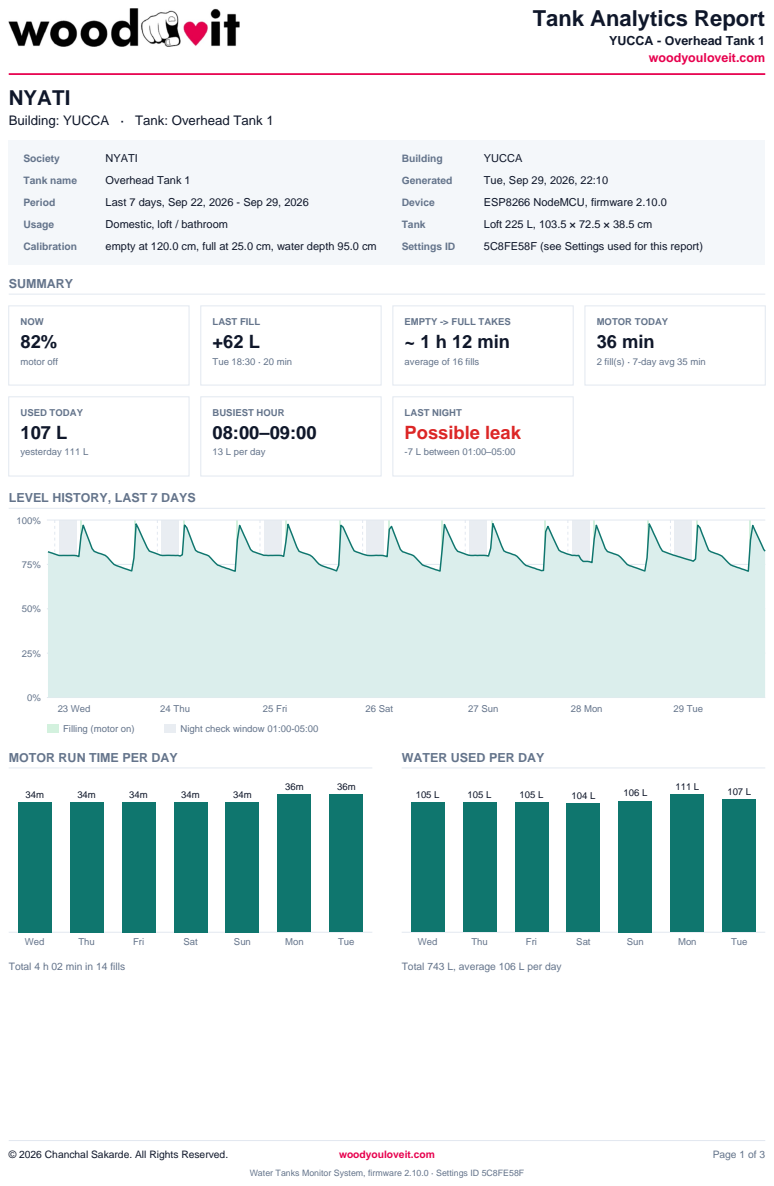
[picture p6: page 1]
Society; NYATI; Building; YUCCA; Tank name; Overhead Tank 1; Generated; Tue, Sep 29, 2026, 22:10; Period; Last 7 days, Sep 22, 2026 - Sep 29, 2026; Device; ESP8266 NodeMCU, firmware 2.10.0; Usage; Domestic, loft / bathroom; Tank; Loft 225 L, 103.5 × 72.5 × 38.5 cm; Calibration; empty at 120.0 cm, full at 25.0 cm, water depth 95.0 cm; Settings ID; 5C8FE58F (see Settings used for this report); SUMMARY; NOW 82%; motor off; LAST FILL +62 L; Tue 18:30 · 20 min; MOTOR TODAY 36 min; USED TODAY 107 L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

YUCCA - Overhead Tank 1
woodyouloveit.com

Building: YUCCA · Tank: Overhead Tank 1

EMPTY -> FULL TAKES
~ 1 h 12 min

average of 16 fills

2 fill(s) · 7-day avg 35 min

LEVEL HISTORY, LAST 7 DAYS

Water Tanks Monitor System, firmware 2.10.0 · Settings ID 5C8FE58F

USAGE BY HOUR OF DAY

00 | 02 | 04 | 06 | 08 | 10 | 12 | 14 | 16 | 18 | 20 | 22
Average per day over 9 days. Busiest hours: 08:00-09:00 (14%), 07:00-08:00 (13%), 20:00-21:00 (11%).

NIGHT LEAK CHECK

Night | Change | Per hour | Result
Tue, Sep 29 | -7 L | 2 L | Possible leak
Mon, Sep 28 | -8 L | 2 L | Water used (one drop)
Sun, Sep 27 | -0 L | 0 L | OK
Sat, Sep 26 | +0 L | 0 L | OK
Fri, Sep 25 | -0 L | 0 L | OK
Thu, Sep 24 | +1 L | 0 L | OK
Wed, Sep 23 | +0 L | 0 L | OK
Level change between 01:00 and 05:00. Possible leak: a steady drop of 1.5 cm (4 L) or more with no fill running. Water used (one drop): most of the drop within one hour, like a tap or flush.

RECENT FILLS (MOTOR RUNS)

Started | | | | | | Duration | | | Added | | Rise speed
Tue, Sep 29, 2026, 18:30 | 20 min | +62 L | 1.3 cm/min
Tue, Sep 29, 2026, 06:00 | 16 min | +50 L | 1.3 cm/min
Mon, Sep 28, 2026, 18:30 | 20 min | +62 L | 1.3 cm/min
Mon, Sep 28, 2026, 06:00 | 16 min | +51 L | 1.3 cm/min
Sun, Sep 27, 2026, 18:30 | 20 min | +62 L | 1.3 cm/min
Sun, Sep 27, 2026, 06:00 | 14 min | +43 L | 1.3 cm/min
Sat, Sep 26, 2026, 18:30 | 20 min | +62 L | 1.3 cm/min
Sat, Sep 26, 2026, 06:00 | 14 min | +43 L | 1.3 cm/min
Fri, Sep 25, 2026, 18:30 | 20 min | +62 L | 1.3 cm/min
Fri, Sep 25, 2026, 06:00 | 14 min | +43 L | 1.3 cm/min

HOW THESE NUMBERS ARE CALCULATED
- Level is measured by the ultrasonic sensor and recorded every 2 minutes.
- Filling (motor on): the level rises faster than 0.5 cm/min. Fills under 3 minutes or 3 cm are ignored. Every fill is counted as the motor.
- Water used: level drops outside fills, ignoring changes smaller than the sensor noise.
- Litres use the tank capacity of 225 L and assume straight tank walls.
© 2026 Chanchal Sakarde. All Rights Reserved. | woodyouloveit.com | Page 2 of 3

SETTINGS USED FOR THIS REPORT

Setting | Value
Settings ID | 5C8FE58F (matches the exported settings file with the same ID)
Society / building / tank | NYATI / YUCCA / Overhead Tank 1
Usage and location | Domestic, loft / bathroom
Tank | Loft 225 L, 103.5 × 72.5 × 38.5 cm
Rated capacity | 225 L
Water depth when full | 34.5 cm
Calibration: sensor to water | empty 120.0 cm, full 25.0 cm (range 95.0 cm)
Resolution | 1 cm of water = ~ 2.4 L (1.1%)
Units in this report | centimetres
Low water alarm | 10% of full
Night leak check | 01:00-05:00, possible leak above 1.5 cm
Fill (motor) detection | rise faster than 0.5 cm/min
Recording | level saved every 2 min, fill detection from 10 s samples
Sensor reading | every 5 s (eco profile), median of 5, trigger pulse 100 microseconds
Power and radio | power saving, transmit power medium (13 dBm), hotspot on demand
Device | ESP8266 NodeMCU, firmware 2.10.0, watertank-3f2a.local
© 2026 Chanchal Sakarde. All Rights Reserved. | woodyouloveit.com | Page 3 of 3

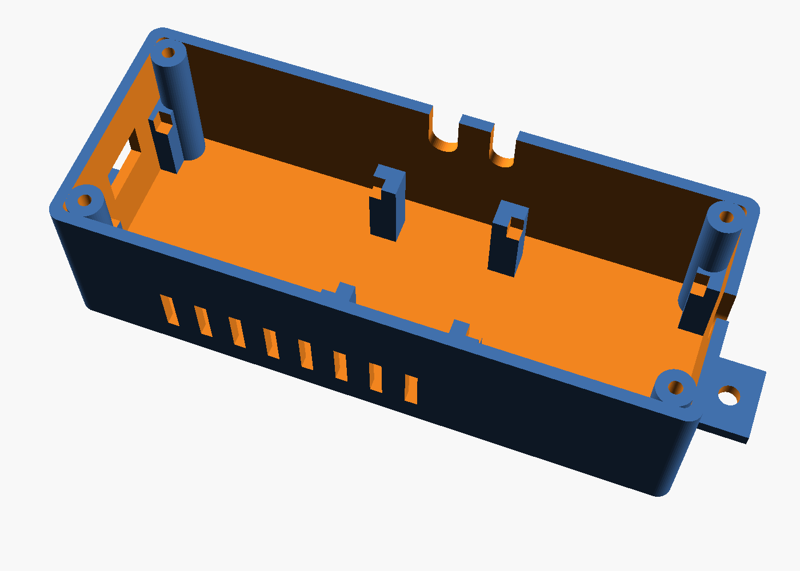
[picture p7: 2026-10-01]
3DprintedBox/view_box_top.png

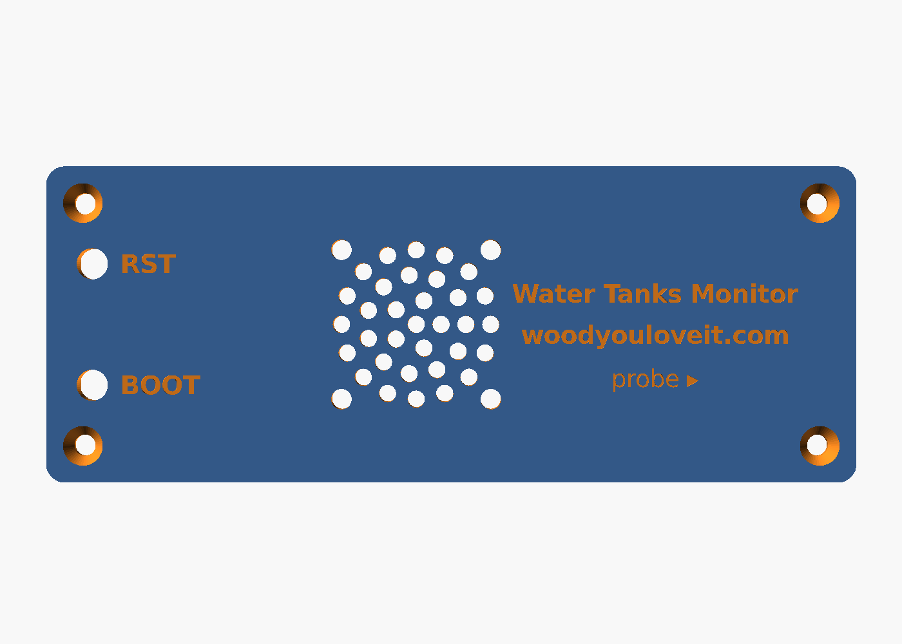
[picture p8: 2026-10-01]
3DprintedBox/view_lid_top.png

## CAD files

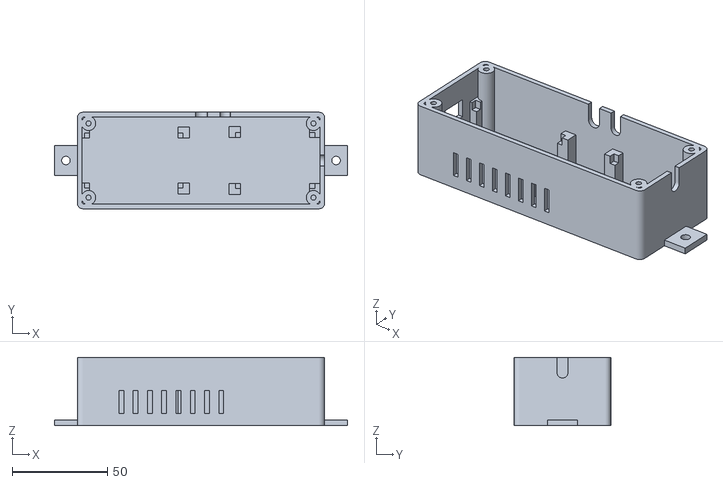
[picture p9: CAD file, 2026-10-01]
3DprintedBox/wtms_enclosure_box.stl
154.1 x 50.8 x 36.0

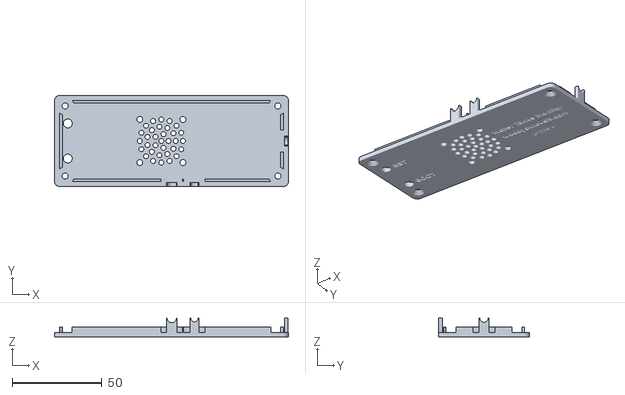
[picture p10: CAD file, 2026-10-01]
3DprintedBox/wtms_enclosure_lid.stl
130.1 x 50.8 x 10.4

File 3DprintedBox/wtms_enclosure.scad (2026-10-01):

/*
  Water Tanks Monitor System - 3D printed enclosure
  ESP32 DevKit V1 (30-pin) + JSN-SR04M-2.0 / AJ-SR04M ultrasonic board + optional 5V fan
  woodyouloveit.com
  Copyright (C) 2026 Chanchal Sakarde. All Rights Reserved, except as granted by the license below.
  This design is free: you can redistribute it and/or modify it under the terms of the GNU General
  Public License, version 3 or (at your option) any later version. No warranty.
  SPDX-License-Identifier: GPL-3.0-or-later

  How to use
  ----------
  1. Measure your boards with calipers and adjust the "Boards" values below if they differ.
  2. Set part = "box", "lid" or "assembly" (preview with boards), then F6 (Render) and F7 (Export STL).
  3. Print the box open side up and the lid top face down. No supports needed.

  Cable passages are slots open at the top of the wall: lay the cable in (connector and all),
  then the lid's tongue closes the slot and clamps the cable.
*/

part = "assembly";            // "box", "lid", "assembly"

// ---------------- Boards (mm) - measure yours ----------------
esp_l = 51.5;                 // ESP32 DevKit V1 30-pin PCB length (USB end to antenna end)
esp_w = 28.5;                 // PCB width
esp_top_h = 4.0;              // tallest part on top of the ESP32 (module shield / USB)
jsn_l = 41.3;                 // JSN-SR04M-2.0 PCB length (spec sheet)
jsn_w = 29.0;                 // PCB width (spec sheet)
jsn_top_h = 12.0;             // tallest part on the JSN board (transformer, capacitor)
pcb_t = 1.6;                  // PCB thickness
standoff_h = 15;              // space under the boards for header pins + Dupont connectors

// ---------------- Cables (mm) - measure yours ----------------
probe_cable_d = 5.0;          // probe cable outer diameter
power_cable_d = 5.5;          // 5 V supply cable (2-core or USB cable)
led_cable_d   = 4.5;          // LED strip 3-wire cable
led_passage   = true;         // third passage for the LED strip wires
usb_window    = true;         // opening for the ESP32 micro-USB (programming / USB power)

// ---------------- Fan ----------------
fan = true;                   // 5 V fan under the lid, blowing out
fan_size = 30;                // 30 (3010 fan, 24 mm holes) or 25 (2507 fan, 20 mm holes) or 40 (4010, 32 mm)
fan_thick = 10;
fan_hole_spacing = fan_size == 25 ? 20 : fan_size == 40 ? 32 : 24;

// ---------------- Enclosure ----------------
wall = 2.4;
floor_t = 2.4;
lid_t = 2.4;
clear = 0.6;                  // clearance around boards
bay = 28;                     // wiring bay between the boards (capacitor, terminal blocks)
inner_w = 46;
inner_h = max(standoff_h + pcb_t + jsn_top_h, standoff_h + pcb_t + esp_top_h + (fan ? fan_thick : 0)) + 3;
inner_l = 1.5 + esp_l + bay + jsn_l + 3;
ears = true;                  // wall-mounting ears
brand = true;                 // engraved text on the lid
$fn = 48;

L = inner_l + 2*wall;
W = inner_w + 2*wall;
H = floor_t + inner_h;

// Board positions (inner coordinates: x from the left inner wall, y from the front inner wall)
esp_x = 1.5;                  // USB end close to the left wall
esp_y = (inner_w - esp_w) / 2;
jsn_x = esp_x + esp_l + bay;
jsn_y = (inner_w - jsn_w) / 2;
board_z = floor_t + standoff_h;

// Cable slot positions
slot_drop = 8;                // cable centre below the top of the wall
probe_slot = [L - wall/2, wall + inner_w/2];               // right wall
power_slot = [wall + esp_x + esp_l + bay*0.35, W - wall/2]; // back wall, wiring bay
led_slot   = [wall + esp_x + esp_l + bay*0.80, W - wall/2]; // back wall
fan_c = [wall + esp_x + esp_l + 4, wall + inner_w/2];       // fan centre (over ESP32 end / bay)
boot_c = [wall + esp_x + 3.5, wall + esp_y + 4.5];          // BOOT button (front side, USB end)
en_c   = [wall + esp_x + 3.5, wall + esp_y + esp_w - 4.5];  // EN (reset) button

// ================= helpers =================
module rbox(s, r=2) {          // rounded-corner box
  hull() for (x=[r, s[0]-r], y=[r, s[1]-r]) translate([x, y, 0]) cylinder(r=r, h=s[2]);
}

// U-slot open at the top of a wall, cable centre at slot_drop below the top
module cable_slot(pos, d, along_x) {
  w = d + 0.8;
  translate([pos[0], pos[1], H - slot_drop])
    rotate([0, 0, along_x ? 90 : 0]) {
      rotate([90, 0, 0]) cylinder(d=w, h=wall*3, center=true);
      translate([-w/2, -wall*1.5, 0]) cube([w, wall*3, slot_drop + 1]);
    }
}
// Lid tongue that closes the slot and clamps the cable lightly
module cable_tongue(pos, d, along_x) {
  w = d + 0.4;
  translate([pos[0], pos[1], 0])
    rotate([0, 0, along_x ? 90 : 0])
      difference() {
        translate([-w/2, -wall/2 + 0.2, -(slot_drop)]) cube([w, wall - 0.4, slot_drop]);
        translate([0, 0, -slot_drop]) rotate([90, 0, 0]) cylinder(d=d - 0.4, h=wall*2, center=true);
      }
}

// Corner cradle: holds a PCB by its corners at height standoff_h
module cradle(bx, by, bl, bw) {
  post = 6; inset = 2.5; above = 2.2;
  for (cx=[0, 1], cy=[0, 1]) {
    px = bx + (cx ? bl - inset : -(post - inset));
    py = by + (cy ? bw - inset : -(post - inset));
    difference() {
      translate([wall + px, wall + py, floor_t - 0.01]) cube([post, post, standoff_h + pcb_t + above]);
      translate([wall + bx - 0.25, wall + by - 0.25, board_z]) cube([bl + 0.5, bw + 0.5, 20]);
    }
  }
}

// ================= box =================
module box() {
  difference() {
    union() {
      rbox([L, W, H], 3);
      // wall-mounting ears (overlap the wall by 1 mm so they print as one piece)
      if (ears) for (side=[0, 1]) translate([side ? L - 1 : -12, W/2 - 8, 0]) difference() {
        cube([13, 16, 3]);
        translate([side ? 7 : 6, 8, -1]) cylinder(d=4.5, h=5);
      }
    }
    // hollow
    translate([wall, wall, floor_t]) rbox([inner_l, inner_w, H], 1.5);
    // cable passages
    cable_slot(probe_slot, probe_cable_d, true);
    cable_slot(power_slot, power_cable_d, false);
    if (led_passage) cable_slot(led_slot, led_cable_d, false);
    // micro-USB opening (left wall, centred on the ESP32)
    if (usb_window)
      translate([-1, wall + esp_y + esp_w/2 - 6.5, board_z + pcb_t + 1.3 - 4.5])
        cube([wall + 2, 13, 9]);
    // intake vents, low in the front wall
    for (i=[0:7]) translate([wall + esp_x + 18 + i*7.5, -1, floor_t + 4]) cube([2.6, wall + 2, 12]);
  }
  // lid screw bosses in the inner corners
  for (x=[wall + 3.5, L - wall - 3.5], y=[wall + 3.5, W - wall - 3.5])
    difference() {
      translate([x, y, floor_t - 0.01]) cylinder(d=7.5, h=inner_h - 0.01);
      translate([x, y, H - 14]) cylinder(d=2.7, h=15);   // M3 self-tapping, 12 mm
    }
  // board cradles
  cradle(esp_x, esp_y, esp_l, esp_w);
  cradle(jsn_x, jsn_y, jsn_l, jsn_w);
}
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

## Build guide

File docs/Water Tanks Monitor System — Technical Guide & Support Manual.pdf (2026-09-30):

# WaterTanks Monitor System — Technical Guide & Support Manual

Sep 30, 2026 · @Chanchal

## 1. Aboutthis guide

This guide covers installing, configuring, operating and troubleshooting the Water Tanks Monitor System (WTMS), firmware 2.10.0, by woodyouloveit.com. It is written for installers and site administrators; residents who only view the dashboard need section 7.1 and section 10.
What the system does. A waterproof ultrasonic sensor mounted above the water measures the distance to the surface. An ESP32 or ESP8266 turns that distance into a fill level, shows it on a WS2812B LED strip (red at the bottom, fading to green at the top), and serves a web dashboard over Wi-Fi with live level, litres, analytics, a PDF report and a connectivity log.
Main parts
Controller: ESP32 DevKit V1 (30-pin) or ESP8266 NodeMCU v1.0 (30-pin). One firmware builds for both.
Sensor: AJ-SR04M (board marked SR04M-2) or JSN-SR04T, with a waterproof probe on a cable.
Display: WS2812B LED strip, 1 to 300 LEDs.
Dashboard: built into the firmware, works offline on the device's own hotspot or on the home Wi-Fi. Tabs: Overview, Analytics, Setup (admin), Log (admin).
Storage: settings in EEPROM (flash); level history, fills and the log in LittleFS (flash), kept across restarts.
Firmware files (all in the water_level_indicator sketch folder): water_level_indicator.ino , dashboard_html.h , event_log.h , history.h , auth.h .

## 2.Technical specifications

Figures are for firmware 2.10.0. Sensor accuracy is the typical value for the AJ-SR04M / JSN-SR04T class; your installation may differ.

Water Tanks Monitor System — Technical Guide & Support Manual

2.1 Controllers

2.2 Sensor (AJ-SR04M / JSN-SR04T)

Item | ESP32 DevKit V1 (30-pin) | ESP8266 NodeMCU v1.0 (30-pin)
Module | ESP-WROOM-32 | ESP-12E
Flash | 4 MB | 4 MB
CPU clock | 80 MHz (power saving) or 240 MHz (performance) | 80 MHz
Logic level | 3.3 V (not 5 V tolerant) | 3.3 V (not 5 V tolerant)
Supply | 5 V on VIN | 5 V on VIN
Program space | 1.2 MB or 1.9 MB per slot, set by the partition scheme | about 1 MB area (OTA needs a program under about 500 KB)
Built-in button used | BOOT (GPIO0) | FLASH (GPIO0)
Item | Value
Supply | 3.0 to 5.5 V (installed on 3.3 V from the board's 3V3 pin)
Operating mode | Trigger / echo (mode 1, resistor position R19 empty)
Trigger pulse | 100 µs default; 50 to 500 µs works; 10 to 20 µs is ignored by the AJ-SR04M
Blind zone | about 20 to 25 cm from the probe face
Range used by the firmware | up to 450 cm; echoes longer than 27 ms (about 460 cm) are treated as no echo
Resolution | about 1 cm from the sensor; shown to 0.1 cm after the median filter
Distance formula | distance (cm) = echo time (µs) × 0.0343 ÷ 2

2.3 LED strip and power

2.4Wi-Fi and network

Item | Value
Strip type | WS2812B, 5 V
Number of LEDs | 1 to 300 (set in the dashboard)
Data line | 3.3 V from the board through a 330 Ω resistor
Current | up to 60 mA per LED at full white; the level display (red/green only) uses less; the dashboard shows an estimate
Power supply | 5 V, at least 2 A for 30 LEDs or 3 A for 60 LEDs
Supply capacitor | 1000 µF, 10 V or higher, across the strip's 5 V and GND
Item | Value
Radio | 2.4 GHz, 802.11 b/g/n
Transmit power | Low 8.5 dBm, Medium 13 dBm (default), High 19.5 dBm (20.5 dBm on ESP8266)
Hotspot name | WTMS-XXXX (chip ID), or WTMS <building> <tank> once named; max 32 characters
Hotspot security | open network; the dashboard itself needs the admin password for any change
Hotspot address | http://192.168.4.1 (captive portal opens the dashboard)
Home network address | http://tank-<building>-<tank>.local or the IP address
Web server | HTTP on port 80; dashboard page about 125 KB, served from flash

2.5 Storage and measurement

## 3.Bill of materials

One set per tank.

Item | Value
Settings storage | EEPROM area, 512 bytes (kept across restarts and OTA updates)
Level history | 1 record every 2 min, 14 days (2 files × 5,040 records × 8 bytes)
Fill records | 2 files × 100 records
Connectivity log | 2 files × 12 KB, about 300 to 400 events
Total flash data | about 107 KB at most
Sensor reading | every 5 s (Eco, default), 2 s, 0.5 s or custom 0.2 to 30 s
Level filter | median of 5 readings (2 s and slower) or 7
Fill detection | from 10-second samples
Qty | Part | Specification | Notes
1 | Controller | ESP32 DevKit V1 (30-pin) or NodeMCU ESP8266 (30-pin) | ESP32 recommended: OTA has more room
1 | Ultrasonic sensor | AJ-SR04M (SR04M-2) or JSN-SR04T, with probe and cable | Check that position R19 on the sensor board is empty
1 | LED strip | WS2812B, 5 V, 30 or 60 LEDs (1 to 300 supported)
1 | Power supply | 5 V DC, 2 A (30 LEDs) or 3 A (60 LEDs) | Do not power the strip through the board or USB
1 | Resistor | 330 Ω | In the LED data line, close to the strip

The 1 kΩ and 2 kΩ echo divider from earlier designs is not needed: the sensor runs on 3.3 V, so its echo output is already 3.3 V.

## 4.Wiring

The sensor runs on 3.3 V from the board, so its echo wire connects directly. The LED strip and the board's VIN take 5 V from the external supply, and all grounds are joined.

4.1ESP32 DevKit V1

The sensor uses four neighbouring pins (3V3, GND, D15, D2), so one 4-pin connector does the job.

Qty | Part | Specification | Notes
1 | Capacitor | 1000 µF electrolytic, 10 V or higher | Across the strip's 5 V and GND; stripe to GND
2 | Female headers | 15-pin | Makes the board removable
3 | Screw terminals | 4-pin (sensor), 3-pin (strip), 2-pin (power)
1 | Perfboard | about 7 × 9 cm
1 | Stand pipe (loft or shallow tanks) | PVC, at least 25 cm tall and 75 mm inside diameter | Keeps the full water line out of the blind zone
1 | Enclosure | ventilated, away from direct sun
— | Hook-up wire | 20 to 22 AWG for 5 V and GND, thinner for signals
From | ESP32 pin | Notes
Sensor "5V" pin | 3V3 | 3.3 V only, never the 5 V supply
Sensor GND | GND (next to 3V3)
Sensor RX (TRIG) | D15 | Must be D15
Sensor TX (ECHO) | D2 | Must be D2

Keep D15 = TRIG and D2 = ECHO. Both are boot strapping pins. D2 must be LOW while uploading over USB; the sensor's echo output rests LOW, so uploads work. Swapped, the sensor's RX input can hold D2 HIGH and uploads fail with "wrong boot mode". A blue LED on D2, if the board has one, flickers with each reading; that is normal.

4.2ESP8266 NodeMCU

Do not use D3, D4 or D8 for external wiring: the board reads them at boot.

4.3Wiring rules

1. Power the strip from the 5 V supply, never through the board or its USB port.
2. Fit the 1000 µF capacitor across the strip's 5 V and GND, stripe to GND.
3. Put the 330 Ω resistor in the data line, close to the strip.
4. Join all grounds: supply, board, strip and sensor.
5. For strips longer than about 60 LEDs, also feed 5 V and GND to the far end.
From | ESP32 pin | Notes
LED strip DIN | G16 (RX2) | Through 330 Ω
5 V supply + | VIN | Also to the strip's 5 V
5 V supply − | GND | Also to the strip's GND
From | NodeMCU pin | Notes
Sensor "5V" pin | 3V3 | 3.3 V only when ECHO is wired directly
Sensor GND | GND
Sensor RX (TRIG) | D5 (GPIO14)
Sensor TX (ECHO) | D6 (GPIO12) | Direct; with the sensor on 5 V, add a 1 kΩ / 2 kΩ divider
LED strip DIN | D2 (GPIO4) | Through 330 Ω
5 V supply + | VIN | Also to the strip's 5 V
5 V supply − | GND | Also to the strip's GND

6. The sensor's pins are labelled RX and TX on the AJ-SR04M board: RX is the trigger input, TX is the echo output.

4.4Wiring diagrams

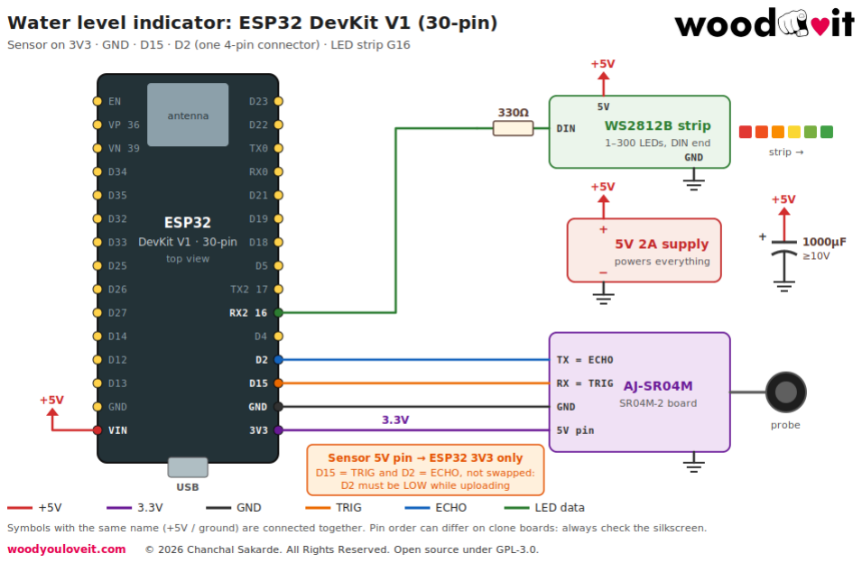
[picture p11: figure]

## 5. Mechanical installation

Mount the probe at the top of the tank, pointing straight down at the water, with the full water line at least 25 cm below the probe face.

5.1 Probe position

Centre of the lid or manhole, pointing vertically down.
Clear of inlet pipes, overflow pipes, ladders, floats and tank walls, which reflect sound and give false readings.
Away from the inlet stream, where splashing and foam scatter the echo.
The cable from the probe to the sensor board must not be cut or extended with thin wire; route it away from the LED strip's power wires.

5.2Blind zone and stand pipe

The sensor cannot measure anything closer than about 20 to 25 cm. If the full water line is closer than that, the level near full is wrong or missing.

Stand pipe for shallow tanks: a PVC pipe at least 25 cm tall and 75 mm inside diameter, standing on the manhole, with the probe at the top pointing down through it. A narrower pipe causes echoes from the pipe wall.
Resolution on shallow tanks: 1 cm of water is about 2.5 % of a loft tank (about 6 L in a 225 L tank). The sensor resolves about 1 cm, so expect the level to move in steps of that size.

5.3 Controller and enclosure

Keep the controller and sensor board dry and out of direct sun.
Give the enclosure a few ventilation holes; the board and its 3.3 V regulator run warm. Mount the LED strip where it can be seen, running bottom to top (set "Strip mounted top-down" in the dashboard if the first LED is at the top).
Leave the board's USB port reachable for the first upload, and the BOOT button reachable for the on-demand hotspot and password reset.

## 6. Software and flashing

The firmware is built with the Arduino IDE and needs one library, Adafruit NeoPixel; Wi-Fi, web server, DNS, mDNS, LittleFS and OTA come with the board package.

6.1 Preparing the Arduino IDE

1. Install the Arduino IDE (2.x).
2. Add the board package:
ESP32: Boards Manager → "esp32" by Espressif.
Tank | Typical height | Mounting
Overhead (roof) tank, 500 L and larger | 80 cm or more | On the lid, if the full line is 25 cm or more below it
Loft / bathroom tank, 150 to 1000 L | 385 to 685 mm | On a stand pipe above the manhole
Underground sump | varies | On the manhole cover, probe away from the inlet and walls

ESP8266: File → Preferences → Additional Boards Manager URLs → http://arduino.esp8266.com/stable/package_esp8266com_index.json , then Boards Manager → "esp8266".
3. Library Manager → install Adafruit NeoPixel.
4. Open water_level_indicator/water_level_indicator.ino . The other four .h files open as tabs and must stay in the same folder.

6.2Tools settings,ESP32 Dev Module

Partition schemes to avoid: Huge APP and all No OTA schemes (no OTA), Minimal 1.3MB (no OTA), any FATFS scheme (no "spiffs" area, so the log and history are kept in memory only), 8M and 16M schemes (the board has 4 MB), RainMaker.
Choosing between the two good schemes: press Verify and read Sketch uses N bytes … Maximum is … bytes . Under about 1,250,000 bytes → Default 4MB with spiffs. Larger → Minimal SPIFFS; its 190 KB is enough, as the firmware stores at most about 107 KB.
Setting | Use | Why
Board | ESP32 Dev Module
Partition Scheme | Default 4MB with spiffs (1.2MB APP / 1.5MB SPIFFS) if the sketch fits; otherwise Minimal SPIFFS (1.9MB APP with OTA / 190KB SPIFFS) | Both keep OTA and a storage area for the log and history
Erase All Flash Before Sketch Upload | Disabled | Enabled wipes settings, Wi-Fi, calibration, history and logs on every upload
CPU Frequency | 240 MHz or 80 MHz | Either; power saving switches to 80 MHz by itself
Core Debug Level | None | Keeps Serial Monitor readable
Upload Speed | 921600 | Use 115200 if uploads fail
Flash Size | 4MB (32Mb)

6.3Tools settings, NodeMCU 1.0 (ESP-12E Module)

6.4 First upload

1. Connect the board by USB, select its Port.
2. Press Upload. If an ESP32 upload stalls at "Connecting…", hold BOOT until writing starts; if it fails with "wrong boot mode", unplug the sensor connector, upload, and plug it back.
3. Open Serial Monitor at 115200 baud. The first lines show Water Tanks Monitor System
2.10.0 | woodyouloveit.com | board esp32 and the copyright line.
4. On a first start, or after a flash erase, the log shows "Flash storage was blank and has been formatted" and Boot #1. That is normal.
Changing the partition scheme needs a USB upload (OTA cannot change it). Settings are kept; history and log start fresh.

## 7. First-time setup

Setup takes about 15 minutes: connect to the device's hotspot, log in as admin, then work down the Setup tab and finish by exporting a settings backup.

Setting | Use
Board | NodeMCU 1.0 (ESP-12E Module)
Flash Size | 4MB (FS:2MB OTA:~1019KB)
Erase Flash | Only Sketch
Upload Speed | 115200 or 921600

7.1 Opening the dashboard

The top LED of the strip blinks blue while the hotspot is on. Type the address with http:// ; https:// pages and other websites cannot be redirected to the dashboard. On a phone, turn off mobile data while on the hotspot. Without logging in, anyone sees the Overview and Analytics tabs.

7.2 Admin login

1. Press Admin in the header.
2. Enter the default password admin .
3. Choose a new password (at least 6 characters, not "admin"). The dashboard does not continue until it is changed.
The Setup and Log tabs appear once logged in.

7.3 Step by step in the Setup tab

1. Wi-Fi settings: press Scan, pick the home network, enter its password, press Connect. The card shows the new address; in automatic hotspot mode the hotspot turns off 30 s later. Reconnect your phone to the home Wi-Fi and open that address.
2. Site details: society or organisation (for example NYATI), building (for example
YUCCA) and tank name (for example Overhead Tank 1). Save, then Restart device to apply the new hotspot name and web address.
3. Usage & tank: Domestic or Commercial; location (overhead, loft / bathroom, underground sump, other); shape; a loft preset or custom dimensions; water depth when full (tank bottom to the overflow pipe, measured); rated capacity in litres. Save tank, then press Recommended settings and confirm.
4. Calibration: use one method from section 9.4: the current-level slider (no need to empty or fill the tank), measurements, or the Empty / Full buttons. While the Setup tab is open, the sensor is read every 0.5 s.
Where you are | Address
Connected to the device's hotspot ( WTMS-XXXX or WTMS <building> <tank> ) | opens by itself; otherwise http://192.168.4.1
On the same home Wi-Fi as the device | http://tank-<building>-<tank>.local, or the IP shown in Setup → Wi-Fi settings

5. Display & sensor: number of LEDs on the strip, brightness (the card shows the supply current needed), low water alarm, strip direction, units for everyone (mm, cm or inch).
6. Power & radio: power saving on, hotspot On demand, transmit power Low or Medium.
7. Update rate: Eco (sensor every 5 s, dashboard every 10 s).
8. Admin & backup: press Export settings and keep the file.

7.4 Checking the installation

Overview shows a plausible level and litres; "Tank at a glance" shows no warnings. Setup → Device shows Log storage: Flash (kept after restart).
Pour or draw some water and watch the level follow within about 15 s (Eco).
The next day, Analytics shows the level history and any fills.

## 8. Configuration reference

All settings are changed by an admin in the dashboard and stored in flash. Distances are stored in cm and tank sizes in mm, whatever unit is displayed.

Card | Setting | Default | Range / options
Site details | Society / organisation | empty | up to 48 characters
Site details | Building, Tank | empty | up to 32 characters each
Usage & tank | Usage | Domestic | Domestic, Commercial
Usage & tank | Tank location | Overhead | Overhead, Loft / bathroom, Underground sump, Other
Usage & tank | Tank shape | Rectangular | Rectangular, Vertical cylinder
Usage & tank | Tank size | Custom | Loft presets 150, 225, 270, 400, 500, 1000 L, or length × width × height / diameter × height, up to 20,000 mm
Usage & tank | Water depth when full | not set | up to 20,000 mm, not more than the tank height

Card | Setting | Default | Range / options
Usage & tank, Analytics | Capacity | 0 (amounts in %) | 0 to 1,000,000 L
Calibration | Empty distance | 120 cm | up to 450 cm
Calibration | Full distance | 25 cm | at least 15 cm; empty − full at least 10 cm
Display & sensor | Units for everyone | cm | mm, cm, inch (each browser can override)
Display & sensor | Number of LEDs | 30 | 1 to 300
Display & sensor | LED brightness | 150 | 5 to 255
Display & sensor | Low water alarm | 10 % | 0 to 50 %
Display & sensor | Strip mounted top-down | off | on / off
Display & sensor | Whole bar one colour | off | on / off
Display & sensor | Sensor trigger pulse | 100 µs | 10 to 1000 µs (AJ-SR04M: 50 to 500)
Analytics settings | Night check window | 01:00 to 05:00 | any start and end hour, not equal
Analytics settings | Leak limit | 1.5 cm | drop in the night window
Analytics settings | Fill detection threshold | 0.5 cm/min | minimum rise speed
Power & radio | Power saving | on | on / off (performance)
Power & radio | Hotspot | Automatic | Automatic, On demand (BOOT), Always on
Power & radio | Transmit power | Medium 13 dBm | Low 8.5, Medium 13, High 19.5 dBm

Recommended settings (Usage & tank card, applied on confirmation):

The Defaults button (Display & sensor) resets calibration, display and analytics settings. It keeps the LED count, capacity, units, update rate, power, transmit power, hotspot mode, site, tank profile and Wi-Fi.

## 9. How measurement works

The level comes from the time an ultrasonic echo takes to return from the water surface, filtered by a median of several readings and scaled between the calibrated empty and full distances.

9.1 One reading

1. The controller holds TRIG (sensor RX) high for the trigger pulse, 100 µs by default.
2. The sensor sends a burst of 40 kHz ultrasound and raises ECHO (sensor TX).
3. ECHO stays high until the echo returns; the controller times it.
4. Distance (cm) = echo time (µs) × 0.0343 ÷ 2. Example: water 50 cm away gives about 2.9 ms.
Card | Setting | Default | Range / options
Update rate | Profile | Eco | Eco, Balanced, Responsive, Custom
Update rate | Custom sensor interval | 5 s | 0.2 to 30 s
Update rate | Custom dashboard refresh | 10 s | 2 to 60 s
Admin | Password | admin (must be changed) | at least 6 characters
| Domestic | Commercial
Night leak check | 01:00 to 05:00 | 22:00 to 06:00
Low water alarm | 15 % (30 % for a sump) | 25 % (30 % for a sump)
Leak limit | 2 % of the water depth, at least 1 cm | same

5. No echo within 27 ms (about 460 cm), or a result over 450 cm, counts as a missed reading.
The AJ-SR04M ignores trigger pulses of 10 to 20 µs; 50 to 500 µs work. Change the pulse only for a different sensor or if "no echo" returns.

9.2Timing

While an admin has the Setup tab open, the sensor is read every 0.5 s (live mode) and returns to the profile 20 s after leaving.
Independent of the profile: fill detection samples every 10 s, history is saved every 2 min, a health line is logged every 5 min.
The dashboard only refreshes while a page is open; with no page open the device serves nothing.

9.3 From distance to level

Level % = (empty distance − distance) ÷ (empty distance − full distance) × 100, limited to 0 to 100 %.
Litres = level × rated capacity (assumes straight tank walls).
The LED bar follows a smoothed level, so it does not flicker; the top lit LED is dimmed in proportion for a smooth bar.
"No echo" (sensor fault) is declared after about 15 s of consecutive missed readings (3 to 10 readings).

9.4 Calibration methods

All three set the empty and full distances; the water depth D = empty − full.

Profile | Sensor reading | Median of | Level follows a change within | "No echo" shown after | Open dashboard refresh
Eco (default) | every 5 s | 5 | about 15 s | about 15 s | every 10 s
Balanced | every 2 s | 5 | about 6 s | about 14 s | every 5 s
Responsive | every 0.5 s | 7 | about 2 s | about 5 s | every 2 s
Custom | 0.2 to 30 s | 5 at 2 s and slower, else 7 | shown in the card | shown in the card | 2 to 60 s

Every method previews the result and refuses a full line closer than 15 cm (warning below 22 cm) or an empty point beyond 450 cm.

9.5 Fill(motor) detection

A fill starts when the level rises faster than the threshold (default 0.5 cm/min) by at least 1.5 cm.
It ends when the rise slows or the tank is full.
Fills shorter than 3 minutes or smaller than 3 cm are ignored.
Every fill is counted as the motor; water from another source that fills the tank is counted too.

9.6Water used
Every drop in level outside a fill, with a small dead band so sensor noise is not counted as use.

9.7 Nightleak check

For each night, the level change in the night window (default 01:00 to 05:00) is compared with the leak limit (default 1.5 cm), when enough readings exist and no fill ran.

Method | You provide | Calculation
Current-level slider | water depth D, how full the tank is now (p %) | empty = live reading + p × D; full = empty − D
Measurements | water depth D, sensor face to full water line G | full = G; empty = G + D
Empty / Full buttons | the tank actually empty or full | the live reading is saved as that point
Result | Rule
OK | drop under half the limit
Watch | drop between half the limit and the limit
Water used (one drop) | drop over the limit, 70 % or more of it within one hour (a tap or flush)

## 10. Analytics and PDF reports

The Analytics tab and the PDF report are open to everyone; only saving analytics settings and clearing history need an admin. The charts are calculated in the browser from the device's stored history, in the viewer's local time.

10.1 Analytics tab

History needs the real time: it comes from the internet on home Wi-Fi, or from the browser when the dashboard is opened on the hotspot. The Overview tab also warns when last night's check found a possible leak.

10.2 PDF report

Press Download PDF report in the Analytics tab. The report covers the last 7 days in A4 and is made in the browser, so it also works offline.

Result | Rule
Possible leak | drop over the limit, slow and steady
Part | Shows
Summary tiles | level now or filling (speed, time to full), last fill, empty → full time, motor time today, water used today, busiest hour, last night's check
Level history | 24 h, 3, 7 or 14 days, fills and night windows shaded, values on hover or tap
Motor run time per day | last 7 days, plus the most recent fills
Water used per day | last 7 days
Usage by hour of day | average use per hour, busiest 3 hours highlighted
Night leak check | last 7 nights with result
Analytics settings (admin) | capacity, fill threshold, night window, leak limit, clear history

Every page carries the copyright line, woodyouloveit.com, the page number, the firmware version and the Settings ID. The file is named wtms-report-<building>-<tank>-<date>.pdf . On the hotspot's pop-up window, open http://192.168.4.1 in the normal browser first, as some pop-ups block downloads.

10.3 Settings ID

The Settings ID is an 8-character fingerprint of the configuration (for example 5B8AF761 ). It appears in the Admin & backup card, in exported settings files and in the report. Matching the ID in a report with an exported settings file shows exactly which configuration produced the report's figures.

## 11. Access control and security

Anyone on the network can view the level and analytics; every change needs the admin password, and the device itself rejects admin actions from viewers (not only the dashboard).

Page | Content
1 | logo, society, building and tank; details table; summary tiles; 7-day level chart; motor time and water used per day
2 | usage by hour; night leak check; recent fills; how the numbers are calculated
3 | Settings used for this report: calibration, capacity, resolution, units, alarm and leak limits, night window, fill threshold, sensor rate, power mode, firmware
| Viewer (no login) | Admin
Overview tab | yes | yes
Analytics tab, PDF report | yes | yes
Save analytics settings, clear history | view only | yes

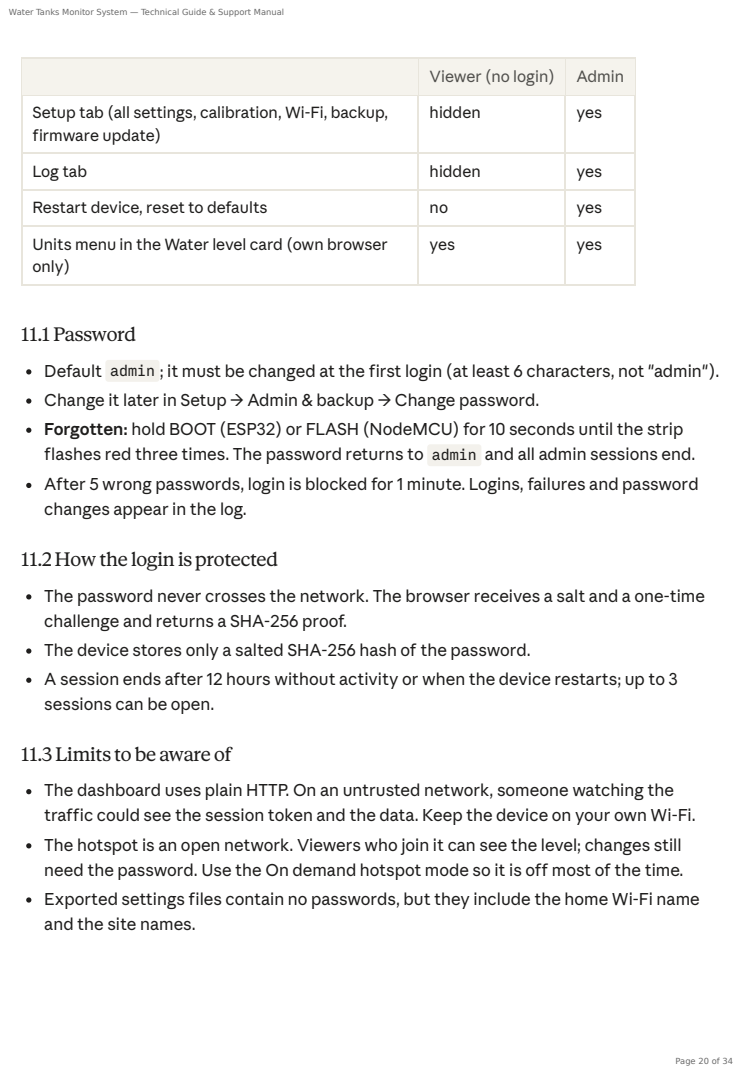
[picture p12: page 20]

Viewer (no login) | Admin

Setup tab (all settings, calibration, Wi-Fi, backup, firmware update) | hidden | yes

Log tab | hidden | yes
Restart device, reset to defaults | no | yes
Units menu in the Water level card (own browser only) | yes | yes

11.1 Password
Default admin ; it must be changed at the first login (at least 6 characters, not "admin").
Change it later in Setup → Admin & backup → Change password.
Forgotten: hold BOOT (ESP32) or FLASH (NodeMCU) for 10 seconds until the strip
flashes red three times. The password returns to admin and all admin sessions end.
After 5 wrong passwords, login is blocked for 1 minute. Logins, failures and password
changes appear in the log.

11.2 How the login is protected
The password never crosses the network. The browser receives a salt and a one-time
challenge and returns a SHA-256 proof.
The device stores only a salted SHA-256 hash of the password.
A session ends after 12 hours without activity or when the device restarts; up to 3
sessions can be open.

11.3 Limits to be aware of
The dashboard uses plain HTTP. On an untrusted network, someone watching the
traffic could see the session token and the data. Keep the device on your own Wi-Fi.
The hotspot is an open network. Viewers who join it can see the level; changes still
need the password. Use the On demand hotspot mode so it is off most of the time.
Exported settings files contain no passwords, but they include the home Wi-Fi name
and the site names.

## 12. Power, heat and production settings

For a device that runs for years, use power saving, the Eco update rate, the On demand hotspot and Low or Medium transmit power; the Wi-Fi radio is by far the largest continuous power user, not the sensor.

12.1 Hotspot modes

Setting | Production value | Effect
Power saving | on | ESP32 CPU at 80 MHz instead of 240 MHz; LED strip refreshed only when a pixel changes; Wi-Fi modem sleep while the hotspot is off; short idle pauses in the main loop; quieter Serial output
Update rate | Eco | sensor every 5 s, open dashboard refreshes every 10 s
Hotspot | On demand | off until the BOOT / FLASH button is pressed; off again after 10 minutes without devices; radio fully off if there is no home Wi-Fi either
Transmit power | Low (Medium if the router is in another room) | less heat and interference
Mode | Behaviour
Automatic | on while there is no home Wi-Fi or it cannot be reached; off 30 s after home Wi-Fi connects
On demand | off until BOOT / FLASH is pressed; off after 10 min without devices; still on at start-up when no home Wi-Fi is saved
Always on | always on; most power and heat

12.2 Other heat sources

### 3.3 V regulator next to the USB socket: it powers the controller and the sensor from 5

V, so warm is normal. Too hot to touch points to a short on 3V3 or the strip drawing power through the board.
Enclosure: ventilation holes; not against the LED strip; out of direct sun.
LED strip: brightness and LED count set the supply current (estimate in Display & sensor). Use a supply rated above that.

## 13. Firmware updates

Firmware can be updated over Wi-Fi from the dashboard (OTA) by an admin; settings, Wi-Fi, admin password, calibration, history and logs are kept.

13.1 Update overWi-Fi(OTA)

1. In the Arduino IDE, with the same Tools settings as the installed build, choose Sketch → Export Compiled Binary.
2. In the sketch folder, open build/<board>/ and take
water_level_indicator.ino.bin (not the .bootloader , .partitions or .merged files).
3. Dashboard → Setup → Firmware update → Choose firmware file.
4. The dashboard checks the file before uploading: an ESP image, Water Tanks Monitor System firmware, built for this board (ESP32 or ESP8266), small enough for the free space. It shows the version and warns about a downgrade.
5. Confirm. A progress bar shows the upload; the device verifies the image, restarts, and the page confirms the new version.
The new firmware is written to the spare program slot. If the upload is interrupted or the image fails verification, the running firmware stays in place.

13.2 Size limits

Board and scheme | Program slot | OTA possible when
ESP32, Default 4MB with spiffs | 1.2 MB | the sketch fits by USB
ESP32, Minimal SPIFFS | 1.9 MB | the sketch fits by USB

The Firmware update card shows the space available. If a build is too big, update once by USB.

13.3 Update by USB

Needed for the first installation, a change of partition scheme, or a build too big for OTA. Keep Erase All Flash Before Sketch Upload: Disabled (ESP32) or Erase Flash: Only Sketch (NodeMCU) so settings survive. Export the settings first as a precaution.

## 14.Backup and restore

Export the settings after setup and after every change; the file restores a device, or sets up an identical one, in a few seconds.

Export: Setup → Admin & backup → Export settings. File name wtms-settings-<building>-<tank>-<date>.json .
Import: Setup → Admin & backup → Import settings → choose the file → confirm. Wi-Fi is not changed. The Settings ID after import matches the file's ID if nothing else was changed.
History and log are not in the backup. Download the log from the Log tab, and PDF reports from Analytics, to keep them.
Board and scheme | Program slot | OTA possible when
ESP8266 NodeMCU, 4MB (FS:2MB OTA:~1019KB) | about 1 MB shared by the running and the new program | the program is under about 500 KB
| Included | Not included
Export settings (JSON) | site names, usage and tank profile, calibration, capacity, low water alarm, analytics settings, units, LED count and brightness, strip options, trigger pulse, power, transmit power, hotspot mode, update rate, Settings ID, firmware version, home Wi-Fi name | Wi-Fi password, admin password, history, log

## 15. Flash storage map

Settings live in a 512-byte EEPROM area and survive OTA updates and partition changes; history and log live in LittleFS and restart empty if its area is erased or moved.

15.1EEPROM (512 bytes)

Each block starts with its own marker. A block with a missing or wrong marker falls back to its defaults, so older firmware's settings are kept and new fields start at their defaults. The home Wi-Fi password is stored as entered, so anyone who can read the board's flash with a USB tool can read it.

15.2 LittleFS files

Offset | Size | Content
0 | 44 bytes | settings: calibration, alarms, display, analytics, power, units, update rate
64 | about 104 bytes | home Wi-Fi name and password
200 | 8 bytes | boot counter
256 | about 120 bytes | site: society, building, tank
384 | 24 bytes | tank profile: usage, location, shape, size, water depth
416 | about 56 bytes | admin password: random salt and SHA-256 hash
File | Record | Limit
/hist.bin , /hist.old.bin | 8 bytes: time, distance (mm), filling flag | 5,040 records each (7 days each, 14 days in total)
/fills.bin , /fills.old.bin | 12 bytes: start, end, start and end distance | 100 records each
/log.txt , /log.old.txt | one line per event | 12 KB each

## 16.Web API reference

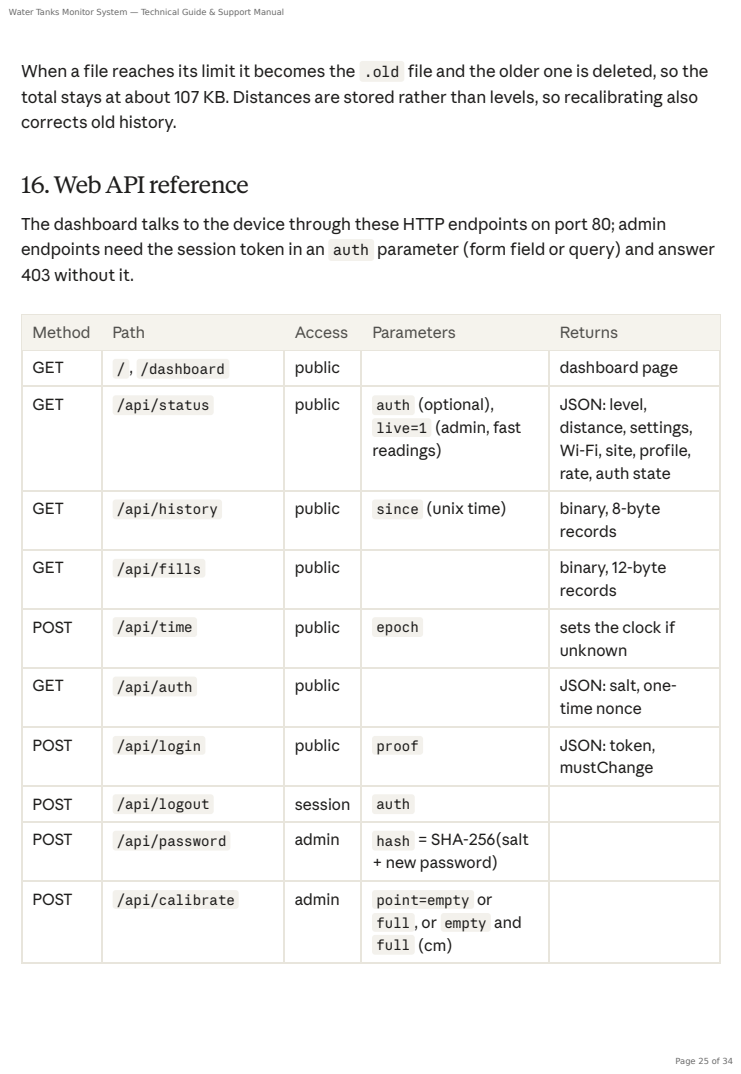
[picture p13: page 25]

When a file reaches its limit it becomes the .old file and the older one is deleted, so the
total stays at about 107 KB. Distances are stored rather than levels, so recalibrating also
corrects old history.

The dashboard talks to the device through these HTTP endpoints on port 80; admin
endpoints need the session token in an auth parameter (form field or query) and answer
403 without it.

Method | Path | Access | Parameters | Returns
GET | / , /dashboard | public | | dashboard page
GET | /api/status | public | auth (optional), live=1 (admin, fast readings) | JSON: level, distance, settings, Wi-Fi, site, profile, rate, auth state

GET | /api/history | public | since (unix time) | binary, 8-byte records

GET | /api/fills | public | | binary, 12-byte records

POST | /api/time | public | epoch | sets the clock if unknown

GET | /api/auth | public | | JSON: salt, one-time nonce

POST | /api/login | public | proof | JSON: token, mustChange

POST | /api/logout | session | auth
POST | /api/password | admin | hash = SHA-256(salt + new password)

POST | /api/calibrate | admin | point=empty or full , or empty and full (cm)

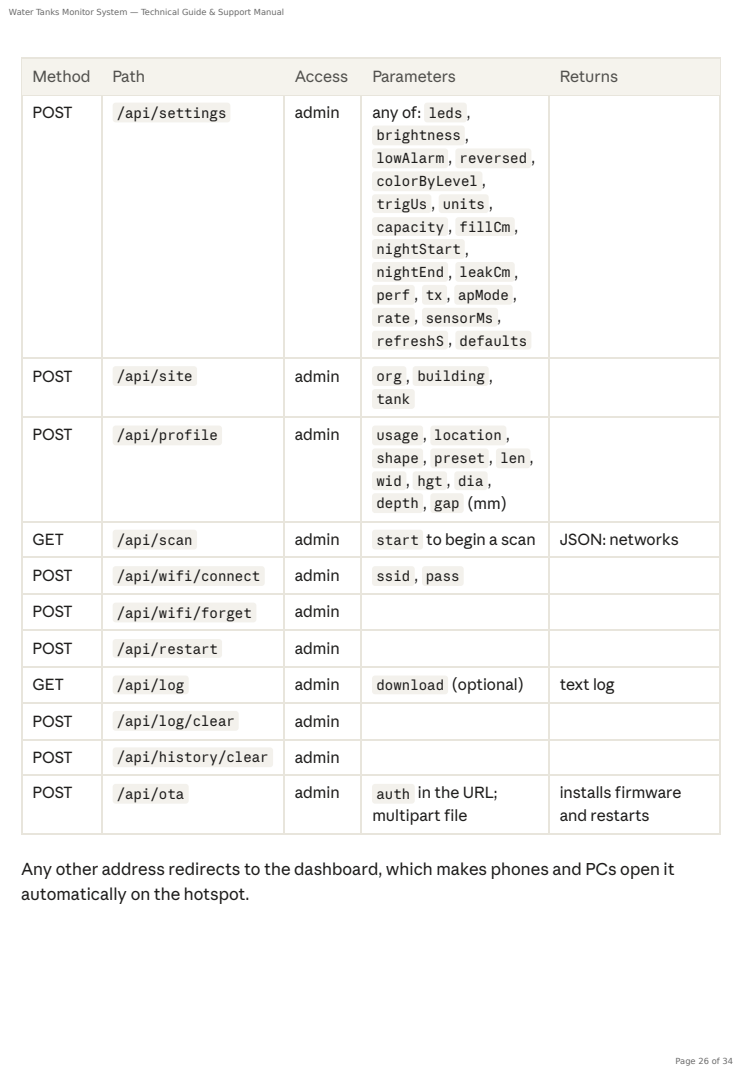
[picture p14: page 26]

Method | Path | Access | Parameters | Returns

POST | /api/settings | admin | any of: leds , brightness , lowAlarm , reversed , colorByLevel , trigUs , units , capacity , fillCm , nightStart , nightEnd , leakCm , perf , tx , apMode , rate , sensorMs , refreshS , defaults

POST | /api/site | admin | org , building , tank

POST | /api/profile | admin | usage , location , shape , preset , len , wid , hgt , dia , depth , gap (mm)

GET | /api/scan | admin | start to begin a scan | JSON: networks

POST | /api/wifi/connect | admin | ssid , pass

POST | /api/wifi/forget | admin

POST | /api/restart | admin
GET | /api/log | admin | download (optional) | text log

POST | /api/log/clear | admin

POST | /api/history/clear | admin
POST | /api/ota | admin | auth in the URL; multipart file | installs firmware and restarts

Any other address redirects to the dashboard, which makes phones and PCs open it
automatically on the hotspot.

## 17. LED indications and log messages

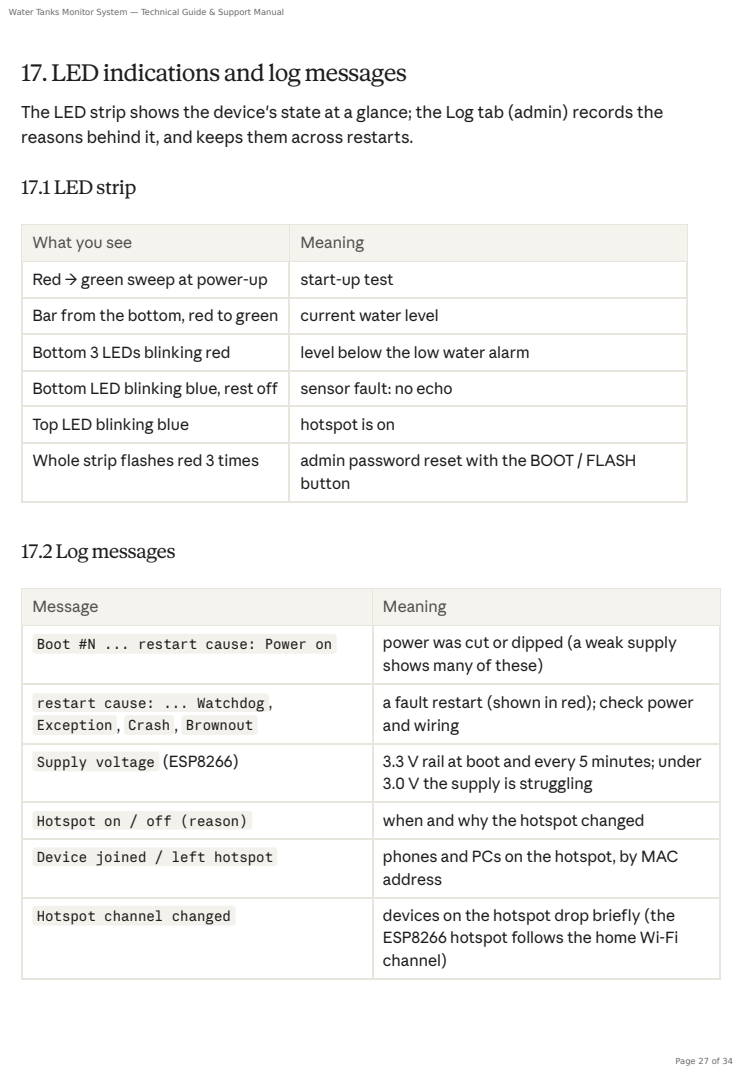
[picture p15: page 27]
17.1 LED strip; 17.2 Log messages

The LED strip shows the device's state at a glance; the Log tab (admin) records the
reasons behind it, and keeps them across restarts.

What you see | Meaning
Red → green sweep at power-up | start-up test
Bar from the bottom, red to green | current water level
Bottom 3 LEDs blinking red | level below the low water alarm
Bottom LED blinking blue, rest off | sensor fault: no echo
Top LED blinking blue | hotspot is on
Whole strip flashes red 3 times | admin password reset with the BOOT / FLASH button

Message | Meaning
Boot #N ... restart cause: Power on | power was cut or dipped (a weak supply shows many of these)

restart cause: ... Watchdog , Exception , Crash , Brownout | a fault restart (shown in red); check power and wiring

Supply voltage (ESP8266) | 3.3 V rail at boot and every 5 minutes; under 3.0 V the supply is struggling

Hotspot on / off (reason) | when and why the hotspot changed
Device joined / left hotspot | phones and PCs on the hotspot, by MAC address

Hotspot channel changed | devices on the hotspot drop briefly (the ESP8266 hotspot follows the home Wi-Fi channel)

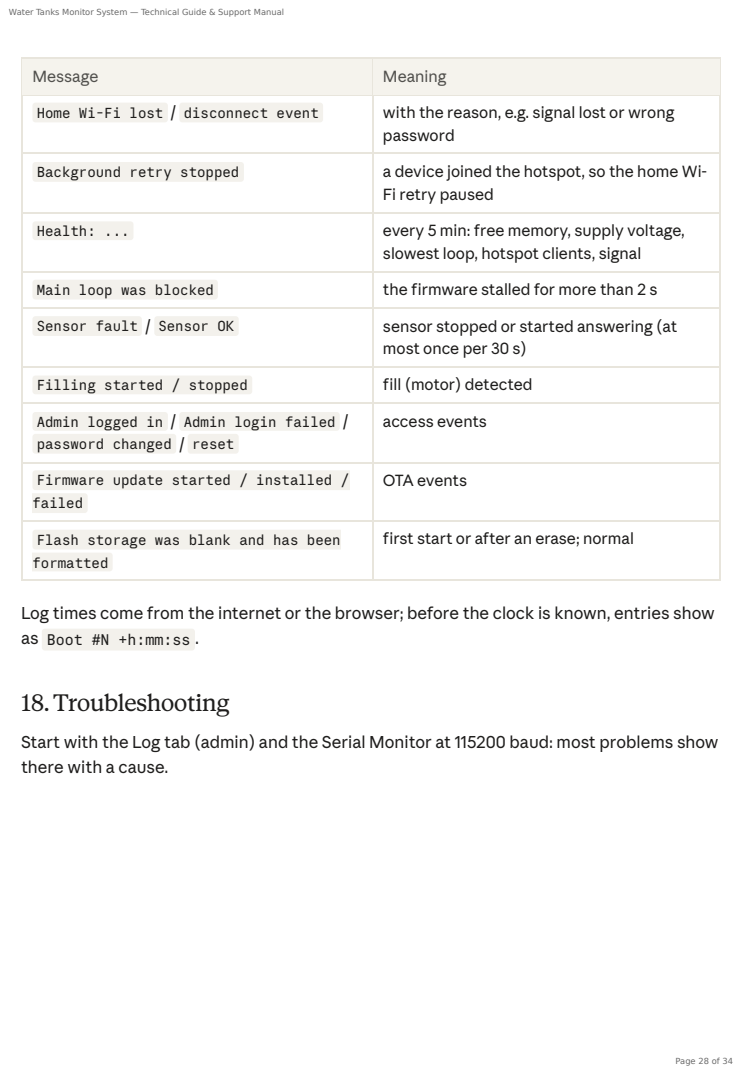
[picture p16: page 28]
18.Troubleshooting

Message | Meaning
Home Wi-Fi lost / disconnect event | with the reason, e.g. signal lost or wrong password

Background retry stopped | a device joined the hotspot, so the home Wi-Fi retry paused

Health: ... | every 5 min: free memory, supply voltage, slowest loop, hotspot clients, signal

Main loop was blocked | the firmware stalled for more than 2 s
Sensor fault / Sensor OK | sensor stopped or started answering (at most once per 30 s)

Filling started / stopped | fill (motor) detected

Admin logged in / Admin login failed / password changed / reset | access events

Firmware update started / installed / failed | OTA events

Flash storage was blank and has been formatted | first start or after an erase; normal

Log times come from the internet or the browser; before the clock is known, entries show
as Boot #N +h:mm:ss .

Start with the Log tab (admin) and the Serial Monitor at 115200 baud: most problems show
there with a cause.

18.1 Sensor and level

18.2 LED strip

Symptom | Likely cause | Fix
Bottom LED blinks blue, dashboard shows "no echo" | RX and TX swapped, loose wire, no common ground, or wrong pins | Check TRIG → sensor RX, ECHO → sensor TX, GND to GND; on ESP32 D15 / D2, on NodeMCU D5 / D6. Replace suspect jumper wires.
"No echo" with correct wiring | trigger pulse too short for the sensor, or sensor in serial mode | Set trigger pulse to 100 µs; check that position R19 on the sensor board is empty
"No echo" only when the tank is nearly full | water inside the blind zone | Raise the probe on a stand pipe so the full line is 25 cm or more below it
Level jumps or reads too high | echo from a pipe, wall, ladder or the stand pipe; probe not vertical | Move the probe to the centre, point it straight down, use a stand pipe at least 75 mm wide
Level always 0 % or 100 %, or wrong | not calibrated, or calibrated for another tank depth | Setup → Calibration (slider or measurements); check "Tank at a glance" warnings
Level changes slowly | Eco update rate (about 15 s) | Normal; use Balanced or Responsive if faster response is needed
Litres wrong but % right | capacity or water depth wrong; tapered tank | Enter the rated capacity and measured water depth; litres assume straight walls
Symptom | Likely cause | Fix
No LEDs, or random colours | no common ground, missing 330 Ω, data on wrong pin | Join grounds; ESP32 G16, NodeMCU D2; add the resistor near the strip

Symptom | Likely cause | Fix
Only part of the strip lights at full level | LED count setting too low | Display & sensor → Number of LEDs
Bar fills from the wrong end | strip mounted top-down | Turn on "Strip mounted top-down"
Far end dim or yellow | voltage drop along the strip | Feed 5 V and GND to both ends
Board resets when LEDs are bright | supply too weak | Use a larger 5 V supply or lower the brightness

18.3Wi-Fi, hotspot and dashboard

18.4 Flashing, storage and updates

Symptom | Likely cause | Fix
Hotspot does not appear | On demand mode | Press BOOT (ESP32) or FLASH (NodeMCU); the top LED blinks blue when it is on
Hotspot disappears | connected to home Wi-Fi (by design), or the board restarts | Check the log: "Hotspot off (connected to home Wi-Fi)" is normal; repeated "Boot #" means power problems
Connected to the hotspot, page does not load | https address or mobile data in use | Open http://192.168.4.1 exactly; turn off mobile data
.local address does not open | some Android phones do not support .local | Use the IP address from Wi-Fi settings
Dashboard unreachable after a router change | saved network no longer exists | Wait about 20 s (automatic mode) or press BOOT, join the hotspot, choose the new network
"Admin session ended" | device restarted or 12 h idle | Log in again
Forgotten admin password | | Hold BOOT / FLASH 10 s until the strip flashes red; log in with admin
"Too many attempts" | 5 wrong passwords | Wait 1 minute
Symptom | Likely cause | Fix
Settings, Wi-Fi or calibration lost after a USB upload | Erase All Flash enabled | Set it to Disabled (ESP32) or Erase Flash: Only Sketch (NodeMCU); import the settings backup

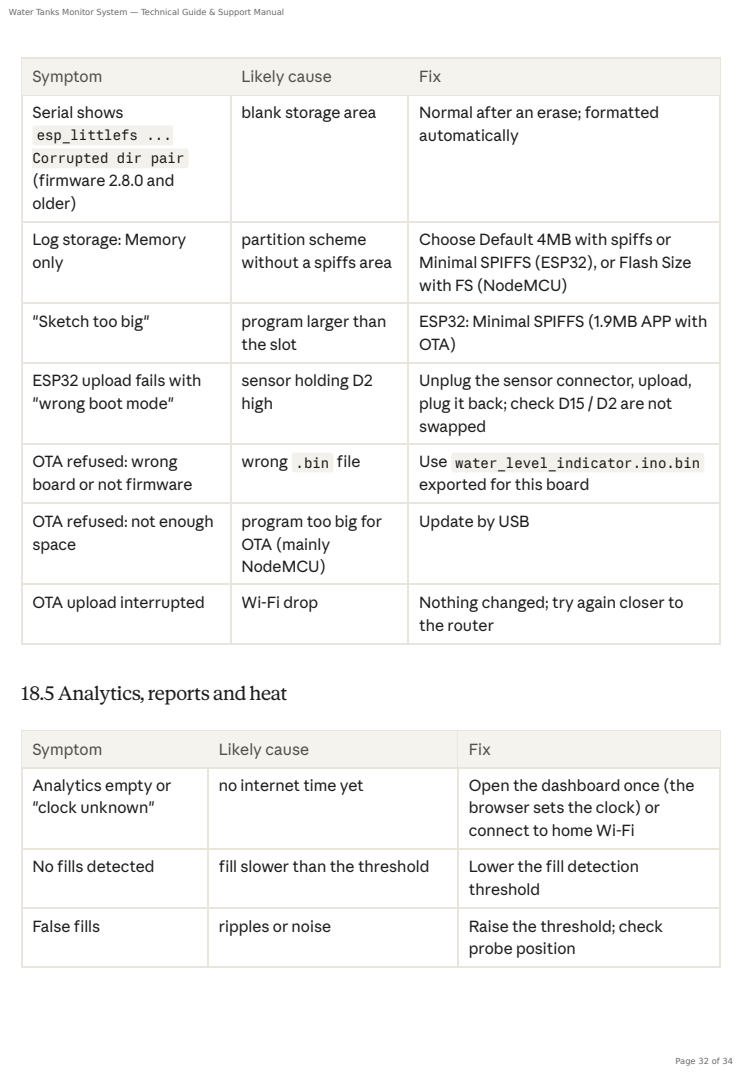
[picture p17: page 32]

Symptom | Likely cause | Fix
Serial shows esp_littlefs ... Corrupted dir pair (firmware 2.8.0 and older) | blank storage area | Normal after an erase; formatted automatically

Log storage: Memory only | partition scheme without a spiffs area | Choose Default 4MB with spiffs or Minimal SPIFFS (ESP32), or Flash Size with FS (NodeMCU)

"Sketch too big" | program larger than the slot | ESP32: Minimal SPIFFS (1.9MB APP with OTA)

ESP32 upload fails with "wrong boot mode" | sensor holding D2 high | Unplug the sensor connector, upload, plug it back; check D15 / D2 are not swapped

OTA refused: wrong board or not firmware | wrong .bin file | Use water_level_indicator.ino.bin exported for this board

OTA refused: not enough space | program too big for OTA (mainly NodeMCU) | Update by USB

OTA upload interrupted | Wi-Fi drop | Nothing changed; try again closer to the router

18.5 Analytics, reports and heat

Analytics empty or "clock unknown" | no internet time yet | Open the dashboard once (the browser sets the clock) or connect to home Wi-Fi

No fills detected | fill slower than the threshold | Lower the fill detection threshold

False fills | ripples or noise | Raise the threshold; check probe position

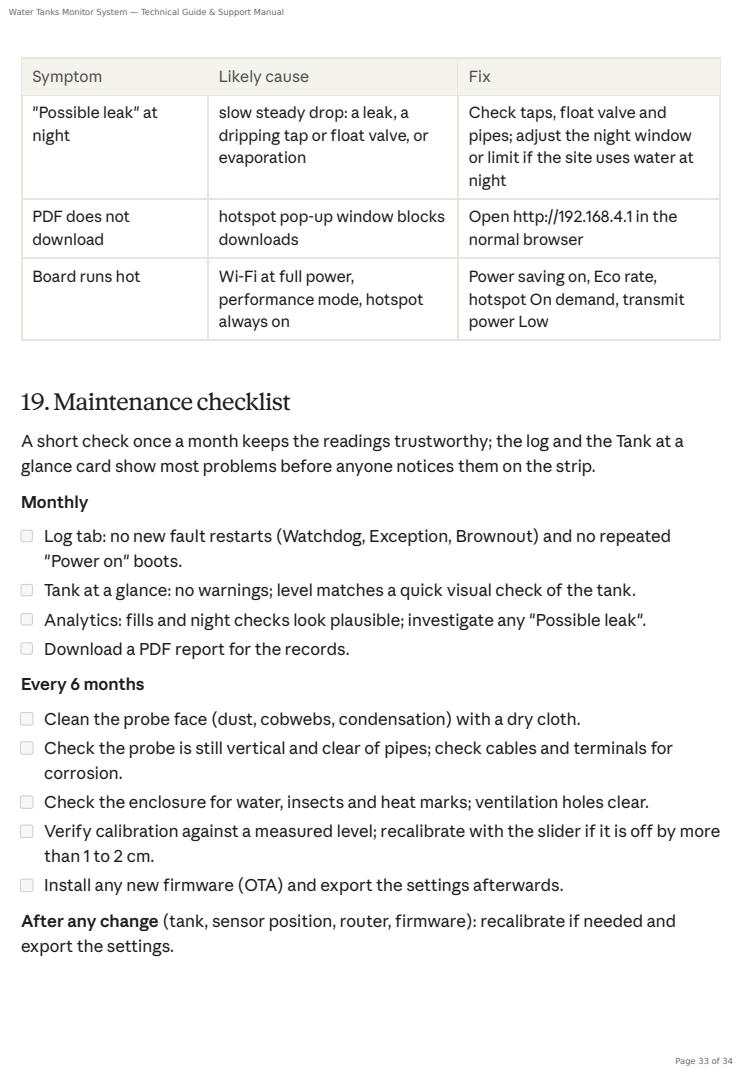
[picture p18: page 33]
19. Maintenance checklist

Symptom | Likely cause | Fix
"Possible leak" at night | slow steady drop: a leak, a dripping tap or float valve, or evaporation | Check taps, float valve and pipes; adjust the night window or limit if the site uses water at night

PDF does not download | hotspot pop-up window blocks downloads | Open http://192.168.4.1 in the normal browser

Board runs hot | Wi-Fi at full power, performance mode, hotspot always on | Power saving on, Eco rate, hotspot On demand, transmit power Low

A short check once a month keeps the readings trustworthy; the log and the Tank at a
glance card show most problems before anyone notices them on the strip.
Monthly
Log tab: no new fault restarts (Watchdog, Exception, Brownout) and no repeated
"Power on" boots.
Tank at a glance: no warnings; level matches a quick visual check of the tank.
Analytics: fills and night checks look plausible; investigate any "Possible leak".
Download a PDF report for the records.
Every 6 months
Clean the probe face (dust, cobwebs, condensation) with a dry cloth.
Check the probe is still vertical and clear of pipes; check cables and terminals for
corrosion.
Check the enclosure for water, insects and heat marks; ventilation holes clear.
Verify calibration against a measured level; recalibrate with the slider if it is off by more
than 1 to 2 cm.
Install any new firmware (OTA) and export the settings afterwards.
After any change (tank, sensor position, router, firmware): recalibrate if needed and
export the settings.

## 20. Licence, copyright and support

© 2026 Chanchal Sakarde. All Rights Reserved, except as granted by the GNU General Public License. woodyouloveit.com.
The firmware is free software under the GNU General Public License, version 3 or (at your option) any later version (SPDX: GPL-3.0-or-later ). It is provided without any warranty. Every source file carries this notice; the full licence is in the LICENSE file. A modified version that is shared must keep the copyright notices and publish its source under the same licence.
Website: woodyouloveit.com
Source code and issues: github.com/ChanchalSakardeQH/WATERTANK-LEVEL-INDICATOR-with-Dashboard (https://github.com/ChanchalSakardeQH/WATERTANK-LEVEL-INDICATOR-with-Dashboard)
When asking for support, include:
1. Board (ESP32 or NodeMCU) and firmware version (Setup → Device).
2. The downloaded log (Log tab → Download).
3. The exported settings file, or its Settings ID.
4. A photo of the wiring and of the probe mounting, if the problem is with readings.

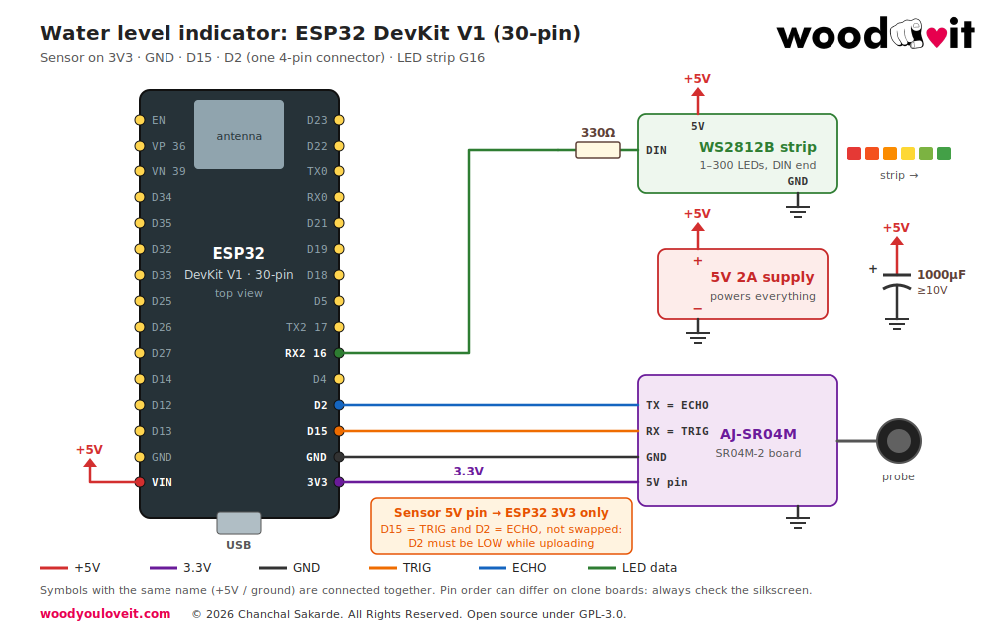
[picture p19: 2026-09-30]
docs/wiring_esp32.png

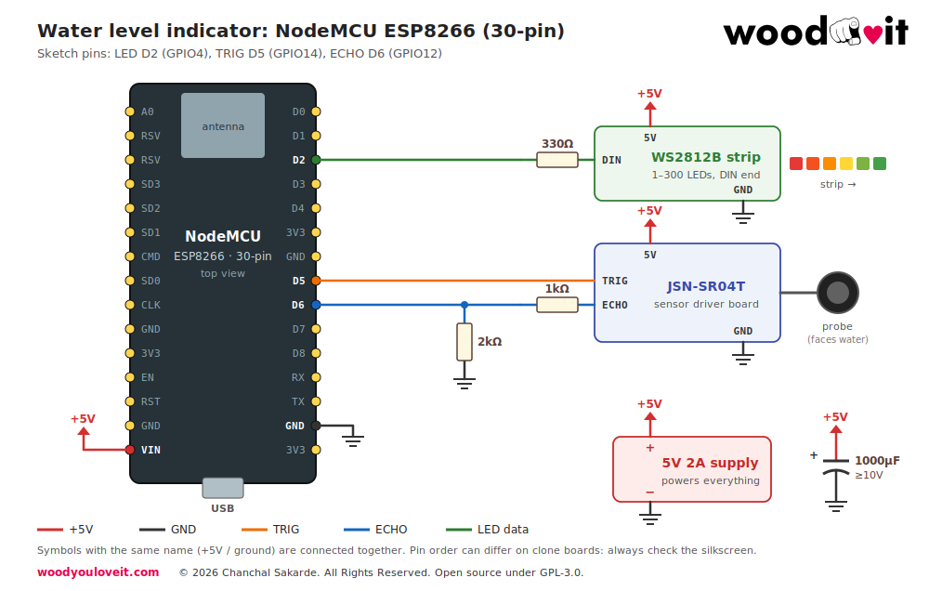
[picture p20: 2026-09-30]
docs/wiring_esp8266.png

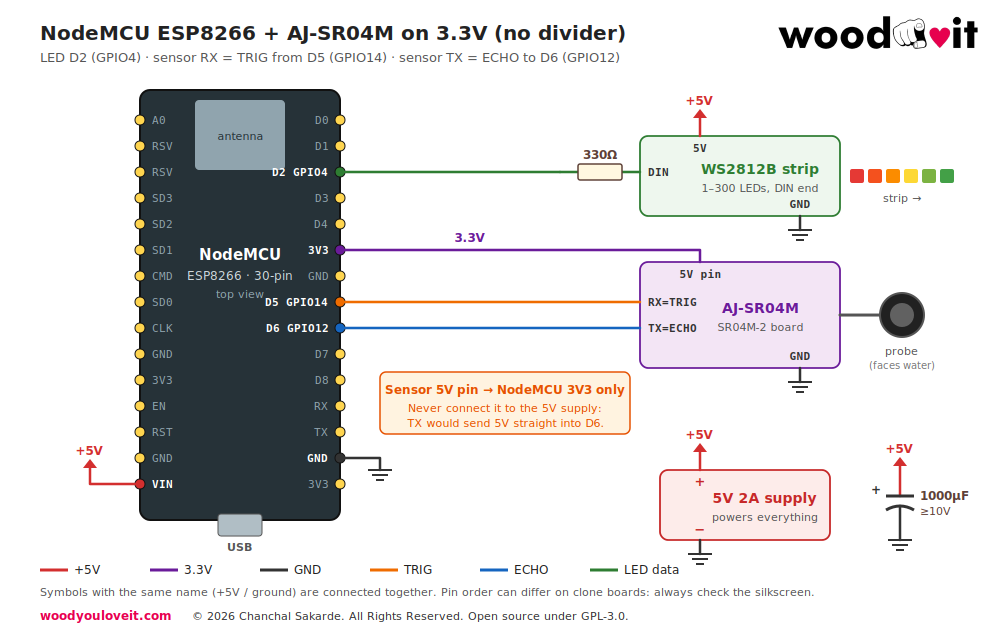
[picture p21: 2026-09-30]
docs/wiring_esp8266_3v3.png

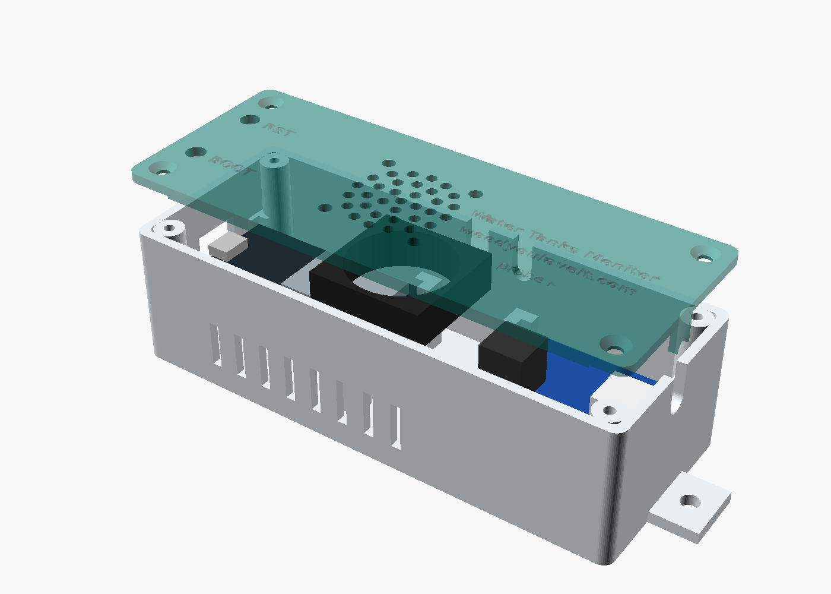
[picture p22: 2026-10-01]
3DprintedBox/view_assembly.png

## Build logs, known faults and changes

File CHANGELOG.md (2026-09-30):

# Changelog

All notable changes to this project are documented in this file.

The format is based on [Keep a Changelog](https://keepachangelog.com/en/1.1.0/),
and this project follows [Semantic Versioning](https://semver.org/spec/v2.0.0.html).

## [Unreleased]

## [2.10.1] - 2026-09-30

### Fixed
- ESP8266 build error "reference to 'Session' is ambiguous": the ESP8266 core exposes its own `BearSSL::Session` globally. The admin session type in `auth.h` is renamed `AuthSession` (and `sessions` → `authSessions`). No change in behaviour; ESP32 builds were not affected.

## [2.10.0] - 2026-09-30

### Added
- **Firmware update over Wi-Fi (OTA)**, admin only: Setup → Firmware update.
  - Upload the `.bin` from "Export Compiled Binary". The dashboard checks the ESP image header, the product and version marker, the board (ESP32 / ESP8266), the size and downgrades before uploading.
  - Upload progress is shown, the image is verified before switching, and the page waits for the restart and confirms the new version.
  - Settings, calibration, history and logs are kept. Endpoint `POST /api/ota`.
- **Update rate profiles** (Setup → Update rate):
  - Eco (**default**): sensor every 5 s, dashboard every 10 s.
  - Balanced: 2 s / 5 s. Responsive: 0.5 s / 2 s. Custom: sensor 0.2–30 s, dashboard 2–60 s.
  - The card shows readings per hour, reaction time and fault detection time.
  - Existing devices switch to Eco after updating.
- **Live mode:** while an admin has the Setup tab open, the sensor is read every 0.5 s for calibration, returning to the profile 20 s later.
- Median window adapts to the rate (5 readings at 2 s and slower, otherwise 7). "No echo" is declared after about 15 s of missed readings (3–10 readings).
- Update rate included in settings export/import and in the report's "Settings used" page.
- Start-up banner carries a board tag (`| board esp32` / `| board esp8266`) used to validate OTA files. `/api/status` adds `rate`, `boardTag`, `otaMax`.

### Changed
- Power saving no longer sets the sensor rate; the Update rate profile does. Performance mode only affects CPU, radio, LED refresh and Serial output.

### Fixed
- Switching tabs refreshes the data immediately instead of waiting for the next scheduled refresh.
- Setup reminder banners are shown to admins only.

## [2.9.0] - 2026-09-30

### Added
- **Admin and viewer access** (`auth.h`):
  - Viewers (no login) see Overview and Analytics only. Analytics settings and Clear history are shown but disabled.
  - Setup and Log tabs, all settings changes, calibration, Wi-Fi, restart and reset need an admin login. The server rejects them with 403 for viewers.
  - Challenge-response login: the password never crosses the network, and a salted SHA-256 hash is stored in EEPROM (offset 416). Up to 3 sessions, 12 h idle timeout, 1-minute lockout after 5 wrong attempts.
  - Default password `admin`, which must be changed at the first login. Hold BOOT/FLASH for 10 s to reset it (the strip flashes red).
  - Endpoints `/api/auth`, `/api/login`, `/api/logout`, `/api/password`. `/api/status` reports `auth.admin` and `auth.mustChange`.
- **Units: mm, cm or inches** for every measurement in the dashboard and PDF report. Device default (Setup → Display & sensor, `units` setting) plus a per-browser override in the Water level card.
- **Settings export and import** (JSON) in the new **Admin & backup** card. Passwords are never exported.
- **Settings ID:** a fingerprint of the configuration, shown in the Admin card, the export file and the PDF.
- PDF report: new **"Settings used for this report"** section (page 3) listing every setting behind the figures, and the Settings ID in the details table and footer.

### Changed
- PDF footer: the GitHub source line is removed. It now shows the firmware version and Settings ID.
- **Defaults** keeps the unit setting.

## [2.8.1] - 2026-09-30

### Fixed
- ESP32: no more red `esp_littlefs ... Corrupted dir pair` / `mount failed (-84)` messages when the flash storage is blank (first upload, or "Erase All Flash Before Sketch Upload" enabled). The storage is formatted quietly and the log records "Flash storage was blank and has been formatted".

### Added
- Log line on the first start (boot #1) explaining that settings are at their defaults and how to keep them across uploads.
- README: recommended Arduino IDE Tools settings for ESP32 and NodeMCU, and troubleshooting for lost settings after an upload.

## [2.8.0] - 2026-09-30

### Added
- **Power & radio** card in Setup.
- **Power saving (production mode)**, on by default: ESP32 CPU at 80 MHz (was 240 MHz), 2 sensor reads per second (was 14), LED strip refreshed at most 4 times a second and only when a pixel changed, Wi-Fi modem sleep while the hotspot is off, a 5 ms idle pause per loop pass, no per-second Serial output, dashboard refresh every 2 s. Performance mode restores the previous behaviour.
- **Wi-Fi transmit power:** Low 8.5 dBm, Medium 13 dBm (default), High 19.5 dBm (previous behaviour).
- **Hotspot modes:** Automatic, Always on, and **On demand**. The BOOT button (ESP32) or FLASH button (NodeMCU) turns the hotspot on, and it turns off after 10 minutes without devices. With no home network and no hotspot, the radio is switched off completely.
- BOOT button press, hotspot mode and power changes are recorded in the connectivity log.
- `/api/status` fields: `apMode`, `perfMode`, `txLevel`, `cpuMhz`. `/api/settings` accepts `apMode`, `perf`, `tx`.

### Changed
- "Keep hotspot always on" switch replaced by the Hotspot setting in Power & radio. The old `apAlways` setting carries over as "Always on".
- **Defaults** keeps the power, transmit power and hotspot settings.
- README and screenshots use "NYATI" as the example society.

## [2.7.0] - 2026-09-30

### Added
- **Setup** tab with all configuration: Usage & tank, Calibration, Site details, Display & sensor, Wi-Fi and Device.
- **Usage & tank** card: Domestic / Commercial, tank location (overhead, loft / bathroom, underground sump, other), shape (rectangular, vertical cylinder), dimensions in mm, water depth when full, capacity with an estimate from the size, mounting tips per location. Stored in flash (`/api/profile`, EEPROM offset 384).
- Loft tank presets: 150, 225, 270, 400, 500 and 1000 L with their outer dimensions.
- **Recommended settings** for Domestic or Commercial use and each tank location: night leak window, low water alarm, leak limit.
- Calibration from a **current-level slider** (no need to empty or fill the tank) and from **measurements** (sensor to full water line + water depth), each with a preview and blind-zone warnings.
- Overview **Tank at a glance** card: water now, space left, capacity in litres, site, usage, tank size, water depth, calibrated range, litres per cm, and setup warnings (not calibrated, blind zone, calibration not matching the tank depth).
- Litres shown under the level percentage.
- PDF report: usage, tank size and calibration in the details table.
- Links to a card (e.g. `#cWifi`) open the tab that holds it.

### Changed
- Overview tab now shows only the level and the tank summary. Calibration, site, display, Wi-Fi and device cards moved to Setup.

## [2.6.1] - 2026-09-30

### Changed
- ESP32 sensor pins moved to **D15 (TRIG, sensor RX)** and **D2 (ECHO, sensor TX)**, so the sensor uses four neighbouring pins: 3V3, GND, D15, D2. LED strip stays on G16.
- ESP32 sensor is powered from 3V3 with the echo wired directly (no divider).
- Sensor diagnostic sketch uses the same ESP32 pins.
- ESP32 wiring diagram redrawn: four straight wires from 3V3/GND/D15/D2, and a note about the strapping pins.

### Notes
- D15 and D2 are ESP32 strapping pins. TRIG must be on D15 and ECHO on D2, not swapped: the echo resting LOW keeps D2 LOW, so USB uploads keep working.

## [2.6.0] - 2026-09-30

### Changed
- Renamed the product from "YUCCA Tank Water Level" to **Water Tanks Monitor System** (WTMS). YUCCA is now just one possible building name.
- Hotspot name: "WTMS <building> <tank>", or "WTMS-XXXX" from the chip ID when not named (was "YUCCA TANK WATER LEVEL").
- Web address: `tank-<building>-<tank>.local`, or `watertank-xxxx.local` when not named (was `yucca-tank.local`). Every tank in a society gets its own.
- Download file names: `wtms-report-<building>-<tank>-<date>.pdf`, `wtms-log-...txt`, `wtms-history.bin`.

### Added
- **Site details** card: society / organisation, building and tank names, saved in flash (EEPROM offset 256, EEPROM size now 512 bytes). Existing calibration, Wi-Fi and settings are kept.
- Site names in the dashboard header, browser tab title and footer, and a banner until the tank is named.
- PDF report: site title (society, building, tank), a site details table, and building and tank in every page header, the PDF properties and the file name.
- Connectivity log download header includes the site names and web address.
- Preview of the hotspot name and web address with a restart prompt when they change.
- `/api/site` endpoint and a `site` object in `/api/status`.

## [2.5.0] - 2026-09-30

### Added
- woodyouloveit.com branding: logo bar at the top of the dashboard (built into the firmware, works offline), page title, heart favicon, and a footer with "© 2026 Chanchal Sakarde. All Rights Reserved.", the website link, the GPL-3.0 link and a source code link.
- **Download PDF report** in the Analytics tab. It's a two-page A4 report generated in the browser with no libraries, so it works offline: logo, website, period, device and tank details, summary tiles, 7-day level chart, motor time and water used per day, usage by hour, night leak check, recent fills and method notes. Every page has the copyright, website, page number and license line. PDF properties: author Chanchal Sakarde, creator woodyouloveit.com.
- GPL-3.0 license notice with copyright and `SPDX-License-Identifier: GPL-3.0-or-later` at the top of every source file (`.ino`, `.h`, diagnostic sketch, diagram generator), plus an HTML comment in the dashboard page.
- `LICENSE` file (GNU GPL v3).
- Brand and copyright line in the Serial Monitor start-up message and in the downloaded connectivity log.
- Logo and copyright line on the wiring diagrams.
- `docs/logo.png` and `docs/sample_report.pdf`.

### Changed
- README: logo, brand and copyright at the top, new PDF report, Branding and License sections.

## [2.4.0] - 2026-09-29

### Added
- Tank analytics (`history.h`): level recorded every 2 minutes in flash (14 days, two rotating files), stored as distance so recalibration also corrects history.
- Fill (motor run) detection on the device from 10-second samples: start, end, rise and speed. Fills are saved and logged ("Filling started / stopped").
- Live filling status in `/api/status`: filling, rise speed, start time, minutes until full.
- Dashboard tabs: **Overview**, **Analytics**, **Log**.
- Analytics tab: summary tiles (now/filling, last fill, empty→full time, motor today, used today, busiest hour, last night), level history chart (24 h / 3 / 7 / 14 days) with fill and night bands and hover values, motor run time per day with recent fills, water used per day, usage by hour of day, night leak check table.
- Night leak check separates a slow, steady drop ("Possible leak") from a single drop within one hour ("Water used (one drop)").
- Leak warning for last night on the Overview tab.
- Analytics settings: tank capacity in litres, fill detection threshold, night window, leak limit, clear history.
- `/api/history`, `/api/fills`, `/api/history/clear` endpoints.
- Clock re-synced from the internet every 10 minutes on home Wi-Fi.

### Changed
- Connectivity log moved to its own tab.
- **Defaults** also keeps tank capacity (it describes the hardware).

## [2.3.1] - 2026-09-29

### Fixed
- Dashboard not loading on the hotspot while the device was retrying the saved home Wi-Fi in the background. The retry makes the ESP search other channels, which stalls hotspot traffic for up to 20 s. A background retry now stops as soon as a device joins the hotspot (logged as "Background retry stopped").

## [2.3.0] - 2026-09-29

### Added
- Connectivity log stored in flash (LittleFS, `event_log.h`), kept across restarts and power cuts: about 300–400 events in two rotating files.
- Logged events: every boot with restart cause and a boot counter, ESP8266 crash details, hotspot on/off with reason, devices joining/leaving the hotspot (MAC), hotspot channel changes, home Wi-Fi connect/lost/failed with the driver's disconnect reason, network scans, calibration and setting changes, sensor faults, main-loop stalls over 2 s.
- Health line every 5 minutes: free memory (and lowest), heap fragmentation and supply voltage on ESP8266, slowest loop, hotspot clients, Wi-Fi signal and channel.
- Real time for log entries: from NTP on home Wi-Fi, or from the browser when the dashboard is opened on the hotspot.
- Dashboard **Connectivity log** card: summary counters, filters (Wi-Fi & hotspot, warnings, restarts), auto-refresh, download as text, clear.
- **Keep hotspot always on** option in Wi-Fi settings.
- Device card: boot count, free memory, supply voltage (ESP8266), log storage.
- `/api/log`, `/api/log/clear`, `/api/time` endpoints.

### Changed
- Serial output now includes every log line prefixed with `[log]`.

## [2.2.0] - 2026-09-29

### Added
- Number of LEDs is a dashboard setting (1–300, default 30), saved in flash. The strip length changes immediately, and LEDs beyond the new length are switched off.
- Dashboard LED preview matches the configured count.
- Power estimate under the LED count: worst-case current at the current brightness and a recommended 5V supply size.

### Changed
- **Defaults** keeps the LED count, since it describes the hardware.
- Settings saved by 2.1.0 or older are kept; the LED count starts at 30.

## [2.1.0] - 2026-09-29

### Changed
- Wi-Fi is now managed by the firmware itself. The WiFiManager library and its menu page are gone.
- Connecting to the hotspot "YUCCA TANK WATER LEVEL" opens the dashboard directly (captive portal on every connectivity check URL).
- Wi-Fi setup moved into the dashboard: new **Wi-Fi settings** card with network scan, connect, show/hide password and forget.
- A new network is saved only after it connects successfully. A failed attempt keeps the previous network.
- After connecting, the dashboard shows the new home address and the hotspot turns off after 30 seconds.
- Dashboard layout: Wi-Fi settings and a separate Device card. A banner links to Wi-Fi settings until a home network is set.

### Added
- Hotspot turns on automatically when home Wi-Fi is lost or unreachable. Home Wi-Fi is retried every minute while nobody is on the hotspot.
- Cause of the last restart (power on, brownout, crash, watchdog...) shown in the Device card and on Serial.
- `/api/scan`, `/api/wifi/connect`, `/api/wifi/forget` endpoints.

### Fixed
- Hotspot dropping after a few minutes: the station interface no longer keeps searching for a network in the background while the hotspot is in use, and Wi-Fi power saving is off.

### Removed
- WiFiManager dependency, `/api/wifi` endpoint and the "Change Wi-Fi" restart flow.

## [2.0.0] - 2026-09-29

### Added
- Web dashboard for desktop and mobile browsers (`dashboard_html.h`), served by the device and working offline.
- Calibration from the dashboard: one-tap "Tank is EMPTY now" / "Tank is FULL now" or manual distances.
- Display and sensor settings from the dashboard: brightness, low water alarm, strip direction, color mode, trigger pulse, factory defaults.
- Wi-Fi setup with WiFiManager: hotspot "YUCCA TANK WATER LEVEL" with a captive portal that opens automatically.
- Wi-Fi control from the dashboard: change network, forget network, restart.
- Dashboard also reachable from the setup hotspot (`/dashboard`) for tanks without home Wi-Fi.
- mDNS name `yucca-tank.local`.
- Settings saved in flash (EEPROM), including calibration.
- Top LED blinks blue while the setup hotspot is open.
- JSON API: `/api/status`, `/api/calibrate`, `/api/settings`, `/api/wifi`, `/api/restart`.

### Changed
- Sensor reading is now non-blocking (one reading every 70ms, median of the last 7) so the web server stays responsive.
- Calibration and display options moved from constants in the sketch to saved settings.
- New library dependency: WiFiManager by tzapu.

### Fixed
- AJ-SR04M returned no echo because it ignores 10-20us trigger pulses. The trigger is now 100us (`TRIG_PULSE_US`).
- Echoes longer than 450cm (the sensor's "no target" pulse) are now treated as invalid instead of an empty tank (`MAX_VALID_CM`).

### Added
- Sensor diagnostic sketch (`tools/sensor_diagnostic/`) that checks the echo line, trigger widths and serial modes.
- Wiring diagram for NodeMCU with the AJ-SR04M powered from 3.3V and no echo divider (`docs/wiring_esp8266_3v3.svg`).
- README section for the 3.3V option, including AJ-SR04M pin mapping (RX = TRIG, TX = ECHO).

## [1.1.0] - 2026-09-29

### Added
- Support for NodeMCU ESP8266 (30-pin). The board is detected automatically from the Arduino IDE selection.
- ESP8266 pin mapping: LED on D2 (GPIO4), TRIG on D5 (GPIO14), ECHO on D6 (GPIO12).
- Compile-time error if a board other than ESP32 or ESP8266 is selected.
- Detected board name printed to Serial Monitor at startup.
- Wiring diagrams for both boards (`docs/wiring_esp32.svg`, `docs/wiring_esp8266.svg`) and the script that generates them.
- README, CHANGELOG and .gitignore.

### Changed
- Sketch moved to `water_level_indicator/water_level_indicator.ino` so the Arduino IDE can open it directly.

## [1.0.0] - 2026-09-29

### Added
- Initial ESP32 version for a JSN-SR04T / AJ-SR04M waterproof sensor and a 30-LED WS2812B strip.
- Red → yellow → green gradient bar that fills from the bottom, with a dimmed top LED for smooth movement.
- Median filter (7 samples) and smoothing of the level reading.
- Low-water alarm: bottom 3 LEDs blink red below 10%.
- Sensor fault indication: bottom LED blinks blue when there is no echo.
- `COLOR_BY_LEVEL` option to color the whole bar by level.
- `STRIP_REVERSED` option for strips mounted top-down.
- Startup sweep animation.

[Unreleased]: https://github.com/ChanchalSakardeQH/WATERTANK-LEVEL-INDICATOR-with-Dashboard/compare/v2.10.1...HEAD
[2.10.1]: https://github.com/ChanchalSakardeQH/WATERTANK-LEVEL-INDICATOR-with-Dashboard/compare/v2.10.0...v2.10.1
[2.10.0]: https://github.com/ChanchalSakardeQH/WATERTANK-LEVEL-INDICATOR-with-Dashboard/compare/v2.9.0...v2.10.0
[2.9.0]: https://github.com/ChanchalSakardeQH/WATERTANK-LEVEL-INDICATOR-with-Dashboard/compare/v2.8.1...v2.9.0
[2.8.1]: https://github.com/ChanchalSakardeQH/WATERTANK-LEVEL-INDICATOR-with-Dashboard/compare/v2.8.0...v2.8.1
[2.8.0]: https://github.com/ChanchalSakardeQH/WATERTANK-LEVEL-INDICATOR-with-Dashboard/compare/v2.7.0...v2.8.0
[2.7.0]: https://github.com/ChanchalSakardeQH/WATERTANK-LEVEL-INDICATOR-with-Dashboard/compare/v2.6.1...v2.7.0
[2.6.1]: https://github.com/ChanchalSakardeQH/WATERTANK-LEVEL-INDICATOR-with-Dashboard/compare/v2.6.0...v2.6.1
[2.6.0]: https://github.com/ChanchalSakardeQH/WATERTANK-LEVEL-INDICATOR-with-Dashboard/compare/v2.5.0...v2.6.0
[2.5.0]: https://github.com/ChanchalSakardeQH/WATERTANK-LEVEL-INDICATOR-with-Dashboard/compare/v2.4.0...v2.5.0
[2.4.0]: https://github.com/ChanchalSakardeQH/WATERTANK-LEVEL-INDICATOR-with-Dashboard/compare/v2.3.1...v2.4.0
[2.3.1]: https://github.com/ChanchalSakardeQH/WATERTANK-LEVEL-INDICATOR-with-Dashboard/compare/v2.3.0...v2.3.1
[2.3.0]: https://github.com/ChanchalSakardeQH/WATERTANK-LEVEL-INDICATOR-with-Dashboard/compare/v2.2.0...v2.3.0
[2.2.0]: https://github.com/ChanchalSakardeQH/WATERTANK-LEVEL-INDICATOR-with-Dashboard/compare/v2.1.0...v2.2.0
[2.1.0]: https://github.com/ChanchalSakardeQH/WATERTANK-LEVEL-INDICATOR-with-Dashboard/compare/v2.0.0...v2.1.0
[2.0.0]: https://github.com/ChanchalSakardeQH/WATERTANK-LEVEL-INDICATOR-with-Dashboard/compare/v1.1.0...v2.0.0
[1.1.0]: https://github.com/ChanchalSakardeQH/WATERTANK-LEVEL-INDICATOR-with-Dashboard/compare/v1.0.0...v1.1.0
[1.0.0]: https://github.com/ChanchalSakardeQH/WATERTANK-LEVEL-INDICATOR-with-Dashboard/releases/tag/v1.0.0

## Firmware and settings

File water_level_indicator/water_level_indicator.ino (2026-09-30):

/*
  Water Tanks Monitor System - main firmware (ESP32 / ESP8266)
  woodyouloveit.com
  Copyright (C) 2026 Chanchal Sakarde. All Rights Reserved, except as granted by the license below.

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
  Source: https://github.com/ChanchalSakardeQH/WATERTANK-LEVEL-INDICATOR-with-Dashboard
  SPDX-License-Identifier: GPL-3.0-or-later
*/

/*
  Water Tanks Monitor System (WTMS)                        firmware 2.10.1
  ESP32 DevKit or ESP8266 NodeMCU + AJ-SR04M / JSN-SR04T + WS2812B strip (1-300 LEDs, set in the dashboard)

  - Each device is named in the dashboard: society / organisation, building, tank.
    The names appear on the dashboard and PDF report, and set the hotspot name
    ("WTMS <building> <tank>") and web address (http://tank-<building>-<tank>.local),
    so several tanks can run side by side.
  - No home Wi-Fi saved: opens the hotspot (default "WTMS-XXXX", XXXX = chip ID).
    Connect to it and the dashboard opens automatically (captive portal).
  - Wi-Fi is set up from the dashboard (Wi-Fi settings: scan, connect, forget).
  - Connected to home Wi-Fi: http://<hostname>.local or the device IP.
    The hotspot turns off 30 s after a successful connection and comes back
    automatically if the home network can't be reached.
  - Calibration, settings and Wi-Fi are saved in flash.
  - Connectivity log (restarts, Wi-Fi, hotspot, sensor) kept in flash for debugging.
  - Tank analytics: 14-day level history, fill (motor run) detection, consumption,
    night leak check. Recorded in flash, analysed in the dashboard.
    Needs a flash layout with a filesystem: Tools > Flash Size "4MB (FS:2MB ...)"
    on ESP8266, or any default partition scheme on ESP32.

  Library (Library Manager): Adafruit NeoPixel
  Wi-Fi, web server, DNS and mDNS come with the ESP32 / ESP8266 board package.
*/

#if defined(ESP32)
  #include <WiFi.h>
  #include <WebServer.h>
  #include <ESPmDNS.h>
  #include <esp_system.h>
  using WebServerT = WebServer;
  #define BOARD_NAME "ESP32"
  #define BOARD_TAG  "esp32"      // also marks firmware files for the OTA check
  #define WIFI_OPEN  WIFI_AUTH_OPEN
  #define LED_PIN   16   // G16 -> 330R -> strip DIN
  // Sensor on 4 neighbouring pins: 3V3, GND, D15, D2 (one 4-pin connector).
  // D15 and D2 are boot strapping pins: TRIG must be on D15 (output) and ECHO on D2,
  // because the sensor's echo rests LOW, which keeps uploading over USB working.
  #define TRIG_PIN  15   // D15 -> sensor TRIG (AJ-SR04M: RX)
  #define ECHO_PIN   2   // D2  <- sensor ECHO (AJ-SR04M: TX), 3.3V only (sensor on 3V3)
#elif defined(ESP8266)
  #include <ESP8266WiFi.h>
  #include <ESP8266WebServer.h>
  #include <ESP8266mDNS.h>
  using WebServerT = ESP8266WebServer;
  #define BOARD_NAME "ESP8266 NodeMCU"
  #define BOARD_TAG  "esp8266"
  #define WIFI_OPEN  ENC_TYPE_NONE
  ADC_MODE(ADC_VCC);     // lets the ESP8266 measure its own supply voltage (A0 is not used)
  #define LED_PIN    4   // D2 -> 330R -> strip DIN
  #define TRIG_PIN  14   // D5 -> sensor TRIG (AJ-SR04M: RX)
  #define ECHO_PIN  12   // D6 <- sensor ECHO (AJ-SR04M: TX)
#else
  #error "Select an ESP32 or ESP8266 board in Tools > Board"
#endif

#include <DNSServer.h>
#if defined(ESP32)
  #include <Update.h>
  #define OTA_ERR() String(Update.errorString())
#else
  #include <Updater.h>
  #define OTA_ERR() Update.getErrorString()
#endif
#include <time.h>
#include <EEPROM.h>
#include <Adafruit_NeoPixel.h>
#include "dashboard_html.h"
#include "event_log.h"
#include "auth.h"
#include "history.h"

#define FW_VERSION  "2.10.1"
#define PRODUCT     "Water Tanks Monitor System"
#define DEFAULT_LEDS 30
#define MAX_LEDS     300

// ================= Timing =================
const float         MAX_VALID_CM     = 450.0;   // longer echoes mean "no target found"
const unsigned long ECHO_TIMEOUT_US  = 27000;   // ~460 cm
const unsigned long LIVE_PING_MS     = 500;     // temporary fast reading while an admin calibrates
const unsigned long LIVE_HOLD_MS     = 20000;   // live mode ends 20 s after the Setup tab stops asking
const unsigned long AP_DEMAND_IDLE   = 600000;  // on-demand hotspot: off after 10 min without devices
const int           BOOT_BTN         = 0;       // BOOT button (ESP32) / FLASH button (NodeMCU), GPIO0
const int           MEDIAN_N         = 7;       // up to 7 readings in the median (5 at slow rates)
const unsigned long CONNECT_TIMEOUT  = 20000;   // give up a Wi-Fi attempt after 20 s
const unsigned long RETRY_INTERVAL   = 60000;   // retry home Wi-Fi every 60 s
const unsigned long AP_OFF_DELAY     = 30000;   // hotspot stays 30 s after connecting
const unsigned long HEARTBEAT_MS     = 300000;  // status line in the log every 5 min

// ================= Saved settings (EEPROM offset 0, same layout as 2.0.0) =================
struct Settings {
  uint32_t magic;
  float    distEmpty;
  float    distFull;
  float    lowAlarm;
  uint16_t trigUs;
  uint8_t  brightness;
  uint8_t  reversed;
  uint8_t  colorByLevel;
  uint8_t  apMode;        // hotspot: 0 automatic, 1 always on, 2 on demand (BOOT button)
  uint16_t numLeds;      // added in 2.2.0; older saves read as invalid -> default
  // added in 2.4.0 (analytics)
  uint32_t capacityL;    // tank capacity in litres, 0 = unknown
  uint8_t  nightStart;   // night leak check window, local hours
  uint8_t  nightEnd;
  uint16_t leakMm;       // night drop that counts as a possible leak (mm)
  uint16_t fillMmMin;    // minimum rise speed that counts as filling (mm/min)
  // added in 2.8.0 (stored in former padding bytes, which read as 0 = the production defaults)
  uint8_t  perfMode;     // 0 power saving (production), 1 performance
  uint8_t  txLevel;      // Wi-Fi transmit power: 0 medium, 1 high, 2 low
  // added in 2.9.0
  uint8_t  units;        // dashboard / report length unit: 0 cm, 1 mm, 2 inch
  // added in 2.10.0 (older saves read as 0 = the Eco profile)
  uint8_t  rateProfile;  // 0 eco, 1 balanced, 2 responsive, 3 custom
  uint16_t sensorMs;     // custom: time between sensor readings
  uint8_t  refreshS;     // custom: dashboard refresh (seconds)
};

// ================= Update rate profiles =================
// sensor interval, dashboard refresh. Eco is the default for long-term installations.
struct RatePreset { uint16_t sensorMs; uint8_t refreshS; };
const RatePreset RATE_PRESETS[3] = {{5000, 10}, {2000, 5}, {500, 2}};
const char* const RATE_NAMES[4] = {"eco", "balanced", "responsive", "custom"};
const uint32_t SETTINGS_MAGIC = 0x59544B32;   // "YTK2"
Settings cfg;

// ================= Saved Wi-Fi (EEPROM offset 64) =================
struct WifiCreds {
  uint32_t magic;
  char     ssid[33];
  char     pass[65];
};
const uint32_t WIFI_MAGIC = 0x59574631;       // "YWF1"
const int      WIFI_ADDR  = 64;
WifiCreds creds;

// ================= Boot counter (EEPROM offset 200) =================
struct BootInfo { uint32_t magic; uint32_t count; };
const uint32_t BOOT_MAGIC = 0x59424F54;       // "YBOT"
const int      BOOT_ADDR  = 200;
uint32_t bootCount = 0;

// ================= Site identity (EEPROM offset 256) =================
struct Identity {
  uint32_t magic;
  char     org[49];       // society / organisation
  char     building[33];
  char     tank[33];
};
const uint32_t ID_MAGIC = 0x5754494E;         // "WTIN"
const int      ID_ADDR  = 256;
Identity ident;
String apName, hostName;                       // derived from the identity at boot

String chipSuffix() {
#if defined(ESP8266)
  uint32_t id = ESP.getChipId();
#else
  uint32_t id = (uint32_t)(ESP.getEfuseMac() >> 24);
#endif
  char b[5];
  snprintf(b, sizeof(b), "%04X", (unsigned)(id & 0xFFFF));
  return String(b);
}

// "Tower A / Tank 1" -> "tower-a-tank-1"
String slug(const String& in) {
  String o;
  for (unsigned int i = 0; i < in.length(); i++) {
    char c = in[i];
    if (c >= 'A' && c <= 'Z') c = c - 'A' + 'a';
    bool ok = (c >= 'a' && c <= 'z') || (c >= '0' && c <= '9');
    if (ok) o += c;
    else if (o.length() && o[o.length() - 1] != '-') o += '-';
  }
  while (o.length() && o[o.length() - 1] == '-') o.remove(o.length() - 1);
  return o;
}

void deriveNames(String& apOut, String& hostOut) {
  String b = ident.building, t = ident.tank;
  b.trim(); t.trim();
  if (b.length() || t.length()) {
    apOut = "WTMS";
    if (b.length()) apOut += " " + b;
    if (t.length()) apOut += " " + t;
    if (apOut.length() > 32) apOut = apOut.substring(0, 32);
    apOut.trim();
    hostOut = "tank";
    String sb = slug(b), st = slug(t);
    if (sb.length()) hostOut += "-" + sb;
    if (st.length()) hostOut += "-" + st;
    if (hostOut.length() > 48) hostOut = hostOut.substring(0, 48);
    while (hostOut.endsWith("-")) hostOut.remove(hostOut.length() - 1);
  } else {
    apOut = "WTMS-" + chipSuffix();
    hostOut = "watertank-" + chipSuffix();
    hostOut.toLowerCase();
  }
}

// ================= Tank profile (EEPROM offset 384) =================
// Usage type, where the tank is, its shape and size. Used by the dashboard for
// calibration from dimensions, litres, recommended settings and the PDF report.
struct TankProfile {
  uint32_t magic;
  uint8_t  usage;         // 0 domestic, 1 commercial
  uint8_t  location;      // 0 overhead (roof), 1 loft / bathroom, 2 underground sump, 3 other
  uint8_t  shape;         // 0 rectangular, 1 vertical cylinder
  uint8_t  preset;        // 0 custom, 1.. preset index in the dashboard
  uint16_t lengthMm, widthMm, heightMm, diaMm;
  uint16_t depthMm;       // water depth when full (bottom -> full / overflow line)
  uint16_t gapMm;         // sensor face -> full water line
};
const uint32_t PROF_MAGIC = 0x5754504B;       // "WTPK"
const int      PROF_ADDR  = 384;
TankProfile prof;

void saveProfile() { prof.magic = PROF_MAGIC; EEPROM.put(PROF_ADDR, prof); EEPROM.commit(); }

void saveIdentity() { ident.magic = ID_MAGIC; EEPROM.put(ID_ADDR, ident); EEPROM.commit(); }

// Keep printable characters only, trimmed, max `size-1` bytes
void setIdField(char* dst, size_t size, String v) {
  v.trim();
  String o;
  for (unsigned int i = 0; i < v.length() && o.length() < size - 1; i++) {
    uint8_t c = v[i];
    if (c >= 0x20 && c != 0x7F && c != '"' && c != '\\') o += (char)c;
  }
  memset(dst, 0, size);
  strncpy(dst, o.c_str(), size - 1);
}

Adafruit_NeoPixel strip(DEFAULT_LEDS, LED_PIN, NEO_GRB + NEO_KHZ800);  // length set from settings
WebServerT server(80);
DNSServer  dns;

// Sensor state
float samples[MEDIAN_N];
int   sampleCount = 0, sampleIdx = 0, failStreak = 0;
float currentDistance = -1;
bool  sensorOK = false;
float smoothedLevel = -1;
bool  blinkState = false;

// Wi-Fi state
enum NetState { NET_NONE, NET_CONNECTING, NET_CONNECTED, NET_FAILED };
NetState net = NET_NONE;
bool   apActive = false, mdnsStarted = false;
String trySsid, tryPass, pendingSsid, pendingPass, netMsg;
bool   tryIsNew = false;
bool   bgRetry = false;          // current attempt is a background retry of the saved network
unsigned long connectStart = 0, lastRetry = 0, apOffAt = 0;
unsigned long pendingConnectAt = 0, pendingForgetAt = 0, restartAt = 0;
String resetReason;
bool   resetIsProblem = false;

// Diagnostics
uint32_t minHeap = 0xFFFFFFFF;
unsigned long loopMax = 0, lastLoopAt = 0;
uint8_t lastChannel = 0;
uint16_t lastStaReason = 0;
unsigned long lastStaReasonAt = 0;
bool lastSensorOK = true;

// Wi-Fi driver events arrive from another context: queue them, log them from loop()
enum { EV_AP_JOIN = 1, EV_AP_LEAVE, EV_STA_DISC };
struct NetEvt { uint8_t type; uint8_t mac[6]; uint16_t reason; };
NetEvt evQ[16];
volatile uint8_t evHead = 0, evTail = 0;
#if defined(ESP8266)
WiFiEventHandler hApJoin, hApLeave, hStaDisc;
#endif

void pushEvt(uint8_t type, const uint8_t* mac, uint16_t reason) {
  uint8_t next = (evHead + 1) % 16;
  if (next == evTail) return;                   // queue full: drop
  evQ[evHead].type = type;
  if (mac) memcpy(evQ[evHead].mac, mac, 6); else memset(evQ[evHead].mac, 0, 6);
  evQ[evHead].reason = reason;
  evHead = next;
}

String macStr(const uint8_t* m) {
  char b[18];
  snprintf(b, sizeof(b), "%02X:%02X:%02X:%02X:%02X:%02X", m[0], m[1], m[2], m[3], m[4], m[5]);
  return String(b);
}

const char* staReasonText(uint16_t r) {
  switch (r) {
    case 2:   return "authentication expired";
    case 3:   return "router ended the session";
    case 4:   return "association expired";
    case 8:   return "disconnected by this device";
    case 15:
    case 204: return "handshake timeout (wrong password?)";
    case 200: return "signal lost (beacon timeout)";
    case 201: return "network not found";
    case 202: return "authentication failed (wrong password?)";
    case 203: return "association failed";
    case 205: return "connection failed";
    default:  return "other";
  }
}

uint32_t supplyMv() {
#if defined(ESP8266)
  return ESP.getVcc();
#else
  return 0;
#endif
}

// ================= Storage =================
void setAnalyticsDefaults();
void setDefaults() {
  cfg.magic = SETTINGS_MAGIC;
  cfg.distEmpty = 120.0;  cfg.distFull = 25.0;  cfg.lowAlarm = 0.10;
  cfg.trigUs = 100;       cfg.brightness = 150;
  cfg.reversed = 0;       cfg.colorByLevel = 0;  cfg.apMode = 0;
  cfg.perfMode = 0;       cfg.txLevel = 0;  cfg.units = 0;
  cfg.rateProfile = 0;    cfg.sensorMs = 5000;  cfg.refreshS = 10;
  cfg.numLeds = DEFAULT_LEDS;
  setAnalyticsDefaults();
}

void setAnalyticsDefaults() {
  cfg.capacityL = 0;  cfg.nightStart = 1;  cfg.nightEnd = 5;
  cfg.leakMm = 15;    cfg.fillMmMin = 5;
}

void saveSettings() { EEPROM.put(0, cfg); EEPROM.commit(); }
void saveCreds()    { EEPROM.put(WIFI_ADDR, creds); EEPROM.commit(); }
bool haveCreds()    { return creds.magic == WIFI_MAGIC && creds.ssid[0] != 0; }

void loadStorage() {
  EEPROM.begin(512);
  EEPROM.get(0, cfg);
  if (cfg.magic != SETTINGS_MAGIC || isnan(cfg.distEmpty) || isnan(cfg.distFull) ||
      isnan(cfg.lowAlarm) || cfg.distEmpty - cfg.distFull < 10) {
    setDefaults();
    saveSettings();
  }
  if (cfg.numLeds < 1 || cfg.numLeds > MAX_LEDS) {   // settings saved by 2.1.0 or older
    cfg.numLeds = DEFAULT_LEDS;
    saveSettings();
  }
  if (cfg.units > 2) { cfg.units = 0; saveSettings(); }
  if (cfg.rateProfile > 3 || cfg.sensorMs < 200 || cfg.sensorMs > 30000 || cfg.refreshS < 2 || cfg.refreshS > 60) {
    if (cfg.rateProfile > 3) cfg.rateProfile = 0;
    if (cfg.sensorMs < 200 || cfg.sensorMs > 30000) cfg.sensorMs = 5000;
    if (cfg.refreshS < 2 || cfg.refreshS > 60) cfg.refreshS = 10;
    saveSettings();
  }
  if (cfg.apMode > 2 || cfg.perfMode > 1 || cfg.txLevel > 2) {
    if (cfg.apMode > 2) cfg.apMode = 0;
    if (cfg.perfMode > 1) cfg.perfMode = 0;
    if (cfg.txLevel > 2) cfg.txLevel = 0;
    saveSettings();
  }
  if (cfg.capacityL > 1000000 || cfg.nightStart > 23 || cfg.nightEnd > 23 || cfg.nightStart == cfg.nightEnd ||
      cfg.leakMm < 2 || cfg.leakMm > 500 || cfg.fillMmMin < 1 || cfg.fillMmMin > 200) {   // saved by 2.3.x or older
    setAnalyticsDefaults();
    saveSettings();
  }

  BootInfo bi;
  EEPROM.get(BOOT_ADDR, bi);
  if (bi.magic != BOOT_MAGIC) { bi.magic = BOOT_MAGIC; bi.count = 0; }
  bi.count++;
  bootCount = bi.count;
  EEPROM.put(BOOT_ADDR, bi);
  EEPROM.commit();
  EEPROM.get(WIFI_ADDR, creds);
  if (creds.magic != WIFI_MAGIC) memset(&creds, 0, sizeof(creds));
  creds.ssid[32] = 0;
  creds.pass[64] = 0;
  EEPROM.get(ID_ADDR, ident);
  if (ident.magic != ID_MAGIC) memset(&ident, 0, sizeof(ident));
  ident.org[48] = 0; ident.building[32] = 0; ident.tank[32] = 0;
  authLoad();
  EEPROM.get(PROF_ADDR, prof);
  if (prof.magic != PROF_MAGIC || prof.usage > 1 || prof.location > 3 || prof.shape > 1) {
    memset(&prof, 0, sizeof(prof));
  }
  deriveNames(apName, hostName);
}

// ================= Ultrasonic (non-blocking) =================
float readDistanceOnce() {
  digitalWrite(TRIG_PIN, LOW);
  delayMicroseconds(5);
  digitalWrite(TRIG_PIN, HIGH);
  delayMicroseconds(cfg.trigUs);         // AJ-SR04M ignores 10-20 us triggers
  digitalWrite(TRIG_PIN, LOW);
  unsigned long us = pulseIn(ECHO_PIN, HIGH, ECHO_TIMEOUT_US);
  if (us == 0) return -1;
  float cm = us * 0.0343 / 2.0;
  return cm > MAX_VALID_CM ? -1 : cm;
}

unsigned long liveUntil = 0;            // live mode while an admin has the Setup tab open
uint16_t sensorIntervalMs() {
  if (liveUntil && millis() < liveUntil) return LIVE_PING_MS;
  return cfg.rateProfile < 3 ? RATE_PRESETS[cfg.rateProfile].sensorMs : cfg.sensorMs;
}
uint8_t refreshSeconds() { return cfg.rateProfile < 3 ? RATE_PRESETS[cfg.rateProfile].refreshS : cfg.refreshS; }
int medianSize()  { return sensorIntervalMs() >= 2000 ? 5 : 7; }              // shorter window when readings are slow
int failLimit()   { return constrain(15000 / (int)sensorIntervalMs(), 3, 10); } // about 15 s of misses, 3..10 readings

float medianOfSamples() {
  float v[MEDIAN_N];
  for (int i = 0; i < sampleCount; i++) v[i] = samples[i];
  for (int i = 1; i < sampleCount; i++) {
    float k = v[i];
    int j = i - 1;
    while (j >= 0 && v[j] > k) { v[j + 1] = v[j]; j--; }
    v[j + 1] = k;
  }
  return v[sampleCount / 2];
}

void sensorTask() {
  static unsigned long last = 0;
  if (millis() - last < sensorIntervalMs()) return;
  last = millis();
  static int lastN = MEDIAN_N;
  int n = medianSize();
  if (n != lastN) { lastN = n; sampleIdx = 0; if (sampleCount > n) sampleCount = n; }

  float d = readDistanceOnce();
  if (d > 0) {
    samples[sampleIdx] = d;
    sampleIdx = (sampleIdx + 1) % n;
    if (sampleCount < n) sampleCount++;
    failStreak = 0;
  } else if (failStreak < 1000) {
    failStreak++;
  }
  if (failStreak >= failLimit()) {
    sensorOK = false; sampleCount = 0; sampleIdx = 0; currentDistance = -1;
  } else if (sampleCount >= 3) {
    currentDistance = medianOfSamples();
    sensorOK = true;
  }
  // Log sensor fault / recovery, at most once per 30 s so a loose wire can't flood the log
  static unsigned long lastSensorLog = 0;
  static int hidden = 0;
  if (sensorOK != lastSensorOK) {
    lastSensorOK = sensorOK;
    if (millis() - lastSensorLog < 30000 && lastSensorLog) { hidden++; return; }
    lastSensorLog = millis();
    String extra = hidden ? " (" + String(hidden) + " changes in between not logged)" : String("");
    hidden = 0;
    if (sensorOK) logWrite('I', "sensor", "Sensor OK: " + String(currentDistance, 1) + " cm" + extra);
    else          logWrite('W', "sensor", "Sensor fault: no echo" + extra);
  }
}

float levelFromDistance(float d) {
  float level = (cfg.distEmpty - d) / (cfg.distEmpty - cfg.distFull);
  return constrain(level, 0.0f, 1.0f);
}

// ================= LEDs =================
uint32_t redToGreen(float t, float dim = 1.0) {
  t = constrain(t, 0.0f, 1.0f);
  uint8_t r, g;
  if (t < 0.5) { r = 255; g = (uint8_t)(t * 2 * 255); }
  else         { r = (uint8_t)((1 - t) * 2 * 255); g = 255; }
  return strip.Color(r * dim, g * dim, 0);
}

// Position of LED i along the strip: 0.0 at the bottom, 1.0 at the top
float posT(int i) { return cfg.numLeds > 1 ? (float)i / (cfg.numLeds - 1) : 1.0f; }

void setLed(int posFromBottom, uint32_t c) {
  int idx = cfg.reversed ? (cfg.numLeds - 1 - posFromBottom) : posFromBottom;
  strip.setPixelColor(idx, c);
}

void drawLevel(float level) {
  float litF = level * cfg.numLeds;
  int fullLeds = (int)litF;
  float partial = litF - fullLeds;
  for (int i = 0; i < cfg.numLeds; i++) {
    float t = cfg.colorByLevel ? level : posT(i);
    if (i < fullLeds)                          setLed(i, redToGreen(t));
    else if (i == fullLeds && partial > 0.05)  setLed(i, redToGreen(t, partial));
  }
  if (level < cfg.lowAlarm)
    for (int i = 0; i < 3 && i < cfg.numLeds; i++) setLed(i, blinkState ? strip.Color(255, 0, 0) : 0);
}

bool ledsForce = true;                  // redraw even if nothing changed (after settings changes)
void displayTask() {
  static unsigned long last = 0;
  static uint8_t lastPix[MAX_LEDS * 3];
  if (millis() - last < (cfg.perfMode ? 100UL : 250UL)) return;
  last = millis();
  blinkState = (millis() / 500) % 2;

  strip.clear();
  if (sensorOK) {
    float level = levelFromDistance(currentDistance);
    smoothedLevel = smoothedLevel < 0 ? level : smoothedLevel + (level - smoothedLevel) * 0.25;
    drawLevel(smoothedLevel);
  } else {
    setLed(0, blinkState ? strip.Color(0, 0, 255) : 0);        // sensor fault
  }
  if (apActive && !blinkState) setLed(cfg.numLeds - 1, strip.Color(0, 0, 160));  // hotspot on
  // Only send data to the strip when a pixel actually changed
  size_t n = (size_t)cfg.numLeds * 3;
  const uint8_t* px = strip.getPixels();
  if (!ledsForce && memcmp(px, lastPix, n) == 0) return;
  memcpy(lastPix, px, n);
  ledsForce = false;
  strip.show();
}
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
void loop() {
  diagTask();
  eventTask();
  wifiTask();
  server.handleClient();
#if defined(ESP8266)
  if (mdnsStarted) MDNS.update();
#endif
  sensorTask();
  fillTask(sensorOK ? currentDistance : -1, cfg.fillMmMin, cfg.distFull);
  historyTask(sensorOK ? currentDistance : -1);
  displayTask();
  buttonTask();

  static unsigned long lastLog = 0;                   // live values on Serial in performance mode only
  if (cfg.perfMode && millis() - lastLog > 1000) {
    lastLog = millis();
    if (sensorOK) Serial.printf("Distance: %.1f cm  Level: %.0f%%\n", currentDistance, smoothedLevel * 100);
    else          Serial.println("Sensor: no echo");
  }

  if (restartAt && millis() > restartAt) ESP.restart();
  delay(cfg.perfMode ? 1 : 5);                         // let the CPU idle between passes
}

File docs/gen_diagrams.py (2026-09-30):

# Water Tanks Monitor System - wiring diagram generator
# woodyouloveit.com
# Copyright (C) 2026 Chanchal Sakarde. All Rights Reserved, except as granted by the license below.
#
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
# Source: https://github.com/ChanchalSakardeQH/WATERTANK-LEVEL-INDICATOR-with-Dashboard
# SPDX-License-Identifier: GPL-3.0-or-later

"""Generate wiring diagrams (SVG) for ESP32 DevKit 30-pin and NodeMCU ESP8266 30-pin."""

C_3V3 = "#6a1b9a"
C_5V, C_GND, C_TRIG, C_ECHO, C_DIN = "#d32f2f", "#333333", "#ef6c00", "#1565c0", "#2e7d32"
FONT = "font-family='Segoe UI,Helvetica,Arial,sans-serif'"
MONO = "font-family='Consolas,Menlo,monospace'"

BX0, BX1, BY0, BY1 = 140, 340, 90, 520

# Brand logo embedded in every diagram (docs/logo.png, resized)
def _load_logo():
    import base64, io, os
    try:
        from PIL import Image
        im = Image.open(os.path.join(os.path.dirname(os.path.abspath(__file__)), "logo.png")).convert("RGBA")
        im = im.resize((400, round(400 * im.height / im.width)), Image.LANCZOS)
        buf = io.BytesIO(); im.save(buf, "PNG", optimize=True)
        return base64.b64encode(buf.getvalue()).decode()
    except Exception:
        return ""
LOGO_B64 = _load_logo()          # board rectangle
def pin_y(i): return 120 + 26 * i                 # i = 0..14


class Svg:
    def __init__(self, w, h):
        self.w, self.h, self.p = w, h, []

    def add(self, s): self.p.append(s)

    def text(self, x, y, s, size=13, anchor="start", weight="normal", fill="#222", mono=False):
        f = MONO if mono else FONT
        self.add(f"<text x='{x}' y='{y}' font-size='{size}' text-anchor='{anchor}' "
                 f"font-weight='{weight}' fill='{fill}' {f}>{s}</text>")

    def wire(self, pts, color, w=2.5):
        d = " ".join(f"{x},{y}" for x, y in pts)
        self.add(f"<polyline points='{d}' fill='none' stroke='{color}' stroke-width='{w}' "
                 f"stroke-linejoin='round' stroke-linecap='round'/>")

    def dot(self, x, y, color):
        self.add(f"<circle cx='{x}' cy='{y}' r='4' fill='{color}'/>")

    def resistor_h(self, x0, x1, y, color, label):
        """Horizontal resistor between x0..x1 on a wire at y."""
        m, w = (x0 + x1) / 2, 44
        self.wire([(x0, y), (m - w / 2, y)], color)
        self.wire([(m + w / 2, y), (x1, y)], color)
        self.add(f"<rect x='{m - w/2}' y='{y - 8}' width='{w}' height='16' rx='2' "
                 f"fill='#fff8e1' stroke='#5d4037' stroke-width='1.5'/>")
        self.text(m, y - 13, label, 12, "middle", "bold", "#5d4037")

    def resistor_v(self, x, y0, y1, color, label):
        m, h = (y0 + y1) / 2, 40
        self.wire([(x, y0), (x, m - h / 2)], color)
        self.wire([(x, m + h / 2), (x, y1)], C_GND)
        self.add(f"<rect x='{x - 8}' y='{m - h/2}' width='16' height='{h}' rx='2' "
                 f"fill='#fff8e1' stroke='#5d4037' stroke-width='1.5'/>")
        self.text(x + 14, m + 4, label, 12, "start", "bold", "#5d4037")

    def gnd(self, x, y):
        """Ground symbol with its top at (x, y)."""
        for i, hw in enumerate((12, 8, 4)):
            yy = y + i * 5
            self.add(f"<line x1='{x-hw}' y1='{yy}' x2='{x+hw}' y2='{yy}' stroke='{C_GND}' stroke-width='2'/>")

    def v5(self, x, y):
        """+5V flag with its bottom at (x, y)."""
        self.add(f"<polygon points='{x-7},{y} {x+7},{y} {x},{y-9}' fill='{C_5V}'/>")
        self.text(x, y - 13, "+5V", 12, "middle", "bold", C_5V)

    def box(self, x, y, w, h, title, sub, fill="#eef3fb", stroke="#3949ab"):
        self.add(f"<rect x='{x}' y='{y}' width='{w}' height='{h}' rx='8' fill='{fill}' "
                 f"stroke='{stroke}' stroke-width='1.8'/>")
        cy = y + h / 2
        self.text(x + w / 2 + 20, cy - 2, title, 14, "middle", "bold", stroke)
        self.text(x + w / 2 + 20, cy + 16, sub, 11, "middle", "normal", "#555")

    def pin_label(self, x, y, s, anchor="start"):
        self.text(x, y + 4, s, 11, anchor, "bold", "#333", mono=True)

    def out(self):
        head = (f"<svg xmlns='http://www.w3.org/2000/svg' xmlns:xlink='http://www.w3.org/1999/xlink' "
                f"viewBox='0 0 {self.w} {self.h}' width='{self.w}' height='{self.h}'>"
                f"<rect width='100%' height='100%' fill='#ffffff'/>")
        if LOGO_B64:   # brand logo, top right
            head += (f"<image x='{self.w - 222}' y='16' width='200' height='33' "
                     f"href='data:image/png;base64,{LOGO_B64}' xlink:href='data:image/png;base64,{LOGO_B64}'/>")
        return head + "".join(self.p) + "</svg>"


def draw_board(s, name, sub, left, right, used):
    """left/right: 15 pin names top->bottom (antenna top, USB bottom). used: {label: color}."""
    s.add(f"<rect x='{BX0}' y='{BY0}' width='{BX1-BX0}' height='{BY1-BY0}' rx='10' "
          f"fill='#263238' stroke='#111' stroke-width='2'/>")
    s.add(f"<rect x='{BX0+55}' y='{BY0+10}' width='90' height='70' rx='4' fill='#90a4ae'/>")
    s.text((BX0 + BX1) / 2, BY0 + 50, "antenna", 11, "middle", fill="#263238")
    s.add(f"<rect x='{(BX0+BX1)/2-22}' y='{BY1-6}' width='44' height='22' rx='3' fill='#b0bec5' stroke='#555'/>")
    s.text((BX0 + BX1) / 2, BY1 + 31, "USB", 11, "middle", "bold", "#555")
    s.text((BX0 + BX1) / 2, 260, name, 15, "middle", "bold", "#ffffff")
    s.text((BX0 + BX1) / 2, 280, sub, 12, "middle", fill="#cfd8dc")
    s.text((BX0 + BX1) / 2, 298, "top view", 11, "middle", fill="#90a4ae")
    for side, names, x in (("L", left, BX0), ("R", right, BX1)):
        for i, n in enumerate(names):
            y = pin_y(i)
            col = used.get(f"{side}{i}")
            s.add(f"<circle cx='{x}' cy='{y}' r='5' fill='{col or '#ffd54f'}' stroke='#111'/>")
            fill = "#ffffff" if col else "#90a4ae"
            anchor, tx = ("start", x + 12) if side == "L" else ("end", x - 12)
            s.text(tx, y + 4, n, 11, anchor, "bold" if col else "normal", fill, mono=True)


def legend(s, y, items=None):
    items = items or [("+5V", C_5V), ("GND", C_GND), ("TRIG", C_TRIG), ("ECHO", C_ECHO), ("LED data", C_DIN)]
    x = 40
    for label, col in items:
        s.add(f"<line x1='{x}' y1='{y}' x2='{x+28}' y2='{y}' stroke='{col}' stroke-width='3'/>")
        s.text(x + 34, y + 4, label, 12)
        x += 110
    s.text(40, y + 26, "Symbols with the same name (+5V / ground) are connected together. "
           "Pin order can differ on clone boards: always check the silkscreen.", 11, fill="#555")
    s.text(40, y + 50, "woodyouloveit.com", 12, weight="bold", fill="#e7004e")
    s.text(192, y + 50, "\u00a9 2026 Chanchal Sakarde. All Rights Reserved. Open source under GPL-3.0.", 11, fill="#333")
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

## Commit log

2026-09-30 Calibration, Power management and Domestic/commercial setup config added
2026-10-01 Adding Encloser Box for Production Ready
    [wtms_enclosure.scad, wtms_enclosure_box.stl, wtms_enclosure_lid.stl]
2026-10-14 1to4 configurable sensors for multi partition on single tank support, Android app 1.2.0 with Admin login
